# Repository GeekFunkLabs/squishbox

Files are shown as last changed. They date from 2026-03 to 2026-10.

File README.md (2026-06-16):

# SquishBox

- [Official Documentation](https://geekfunklabs.github.io/squishbox)
- [Source Repository](https://github.com/GeekFunkLabs/squishbox)

The SquishBox is a compact add-on board and enclosure for Raspberry Pi
(primarily Pi 3B+ and Pi 4) that combines:

- high-quality stereo DAC with 1/4" outputs
- MIDI in/out via TRS minijacks
- 16x2 character LCD
- pushbutton rotary encoder
- breakout GPIO for extra controls, LEDs, and peripherals

This creates a portable embedded platform for audio projects such as synths,
sound modules, pedalboard utilities, sequencers, and music players.

The software package includes ready-to-run applications plus a simple Python API
for building your own.

## Building/Obtaining

This repository includes schematics, PCB fabrication files, BOMs, and enclosure
models for users who want to build their own hardware.

Kits and pre-built units are also available from the Geek Funk Labs
[store](https://geekfunklabs.com/store).

## Installing

The SquishBox software is targeted for a Pi 3B+/4 running Raspberry Pi OS
(64-bit, based on Debian 13 "Trixie") or newer.
Other platforms may work but are not officially tested.

Before installing (even on a fresh system) it's advisable to first run
`sudo apt update && sudo apt upgrade` to update your audio stack.

To run the install script, log in as a regular user and enter:

```bash
bash <(curl -sL geekfunklabs.com/squishbox)
```

Answer the prompts, wait for install to complete,
and reboot the Pi to activate the LCD/button interface.

## Using the SquishBox

On first boot, the SquishBox starts a launcher that lets the user choose
an app to run or modify system settings.
Selections can be made by turning the rotary encoder.
Tapping the rotary encoder confirms a choice.
Pressing and holding the encoder will cancel or return to the previous
screen in most situations.
To safely shut down the SquishBox before disconnecting power,
use the "Shutdown" option in the "Exit" menu.

## Writing SquishBox Apps

The squishbox python package provides access to the LCD,
controls (buttons/encoders), outputs,
and a set of menu-driven interaction helpers.
Here is a simple example app:

```python
import squishbox

sb = squishbox.SquishBox()
card = "hw:sndrpihifiberry"

sb.lcd.clear()
sb.lcd.write("Audio Test", row=0)
while True:
    i, option = sb.menu_choose(["Noise", "Sine", "Exit"], row=1)
    if option == "Noise":
        sb.shell_cmd(f"speaker-test -l2 -c2 -D{card}")
    elif option == "Sine":
        sb.shell_cmd(f"speaker-test -l2 -c2 -tsine -D{card}")
    elif option == "Exit":
        break
```

## Support and Feature Requests

The SquishBox is under active development, and feature requests are
welcome. 

Please post requests/questions to Discussions on GitHub,
and open issues or pull requests for bugs.

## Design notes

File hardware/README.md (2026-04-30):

# SquishBox Hardware

This directory contains the design and fabrication files for the SquishBox PCB and enclosure. These files are sufficient to fabricate the PCB, source components, and 3D-print a complete enclosure.

Editable design files are also provided to support modification and customization. If anything is missing or unclear, please open a GitHub issue or contact [albedozero@geekfunklabs.com](mailto:albedozero@geekfunklabs.com).

## Directory Structure

```shell
hardware/
  pcb/
    fabrication/    # Gerbers, drill files, pick-and-place, BOM
    kicad/          # KiCad source design files
  enclosure/
    print/          # STL and 3MF files for slicing
    freecad/        # FreeCAD source design files
    step/           # STEP files for other CAD software
```

## PCB Details

The fabrication files include only surface-mount components for automated assembly. Through-hole components are intended to be sourced separately and soldered by hand.

Insert through-hole components from the side matching the silkscreen outlines.

Install the LCD module last, as it blocks access to several solder points.

### P1 Header

Unused pins from the Raspberry Pi GPIO header are broken out to P1 for attaching additional buttons/outputs. Pins 4 and 7 are connected to ground through 1k resistors, to allow connecting LEDs without additional components.

| P1 pin | pad shape | function |
|---|---|---|
|  1 | diamond | 5V |
|  2 | diamond | 3.3V |
|  3 | circle | GPIO4 |
|  4 | notched | 1k → GND |
|  5 | circle | GPIO2 (I2C SDA) |
|  6 | circle | GPIO3 (I2C SCL) |
|  7 | notched | 1k → GND |
|  8 | circle | GPIO23 |
|  9 | circle | GPIO24 |
|  10 | circle | GPIO10 |
|  11 | circle | GPIO25 |
|  12 | circle | GPIO9 |
|  13 | circle | GPIO11 |
|  14 | square | GND |

## Case Details

All parts are designed to be printed flat-side down without supports.

* PLA is sufficient, other materials may be used for desired traits
* Infill amount is not critical due to the small interior volume
* Use at least 2–3 wall layers for adequate strength

Three enclosure variants are provided:

* **basic** — Fits Raspberry Pi 3 Model B+ / Raspberry Pi 4 Model B. A Raspberry Pi 5 can fit, but not with the standard fan installed.
* **deluxe** — Fits Pi 3/4 and includes mounting points for two momentary footswitches and two LEDs, which can be connected to the P1 header on the SquishBox PCB.
* **mini** — Fits Raspberry Pi Model A+, with an enlarged cutout to accommodate wide USB cables or adapters.

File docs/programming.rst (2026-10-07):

Programming
===========

This page is a practical primer for customizing/writing SquishBox apps.

Instead of dealing directly with GPIO timing, LCD protocols,
encoder debouncing, or event queues, applications interact with
a single high-level object

.. code-block:: python

   import squishbox
   sb = squishbox.SquishBox()

From there you can:

* Write text to the LCD
* Read knob and button actions
* Present menus and prompts
* Edit text from the front panel
* Control LEDs and outputs
* Launch shell commands
* Build complete standalone hardware applications

Application Model
-----------------

Most SquishBox programs follow a simple pattern:

1. Create a ``SquishBox()`` instance
2. Start the synth/audio process
3. Draw something on the LCD
4. Wait for user input
5. Respond to that input
6. Repeat until exit

Example:

.. code-block:: python

    import squishbox

    sb = squishbox.SquishBox()
    sb.lcd.clear()
    sb.lcd.write("My Cool Synth", row=0)

    i = 0
    synth = start_synth()
    synth.select_patch(i)

    while True:
        i, action = sb.menu_choose(synth.patchnames, i=i)

        if action == None:
            break
        else:
            synth.select_patch(i)

Configuration Files
^^^^^^^^^^^^^^^^^^^

The main SquishBox configuration file ``squishboxconf.yaml`` is intended
to allow the user to change global behavior without modifying code.

The ``controls`` section defines named inputs such as buttons and encoders.
Each item describes the hardware type, GPIO settings, and event bindings.

* ``actions`` Links events to SquishBox UI actions:

  * ``inc``/``dec`` change a value/option
  * ``select`` do/confirm
  * ``back`` cancel/return
  
* ``messages`` Emits MIDI messages in response to events.
  Control change, note, and program change messages are implemented.
  Message format is ``{ctrl|note}:<channel>:<number>:<value>``
  or ``{prog}:<channel>:<value>``.

.. code-block:: yaml

    controls:
      knob1:
        type: encoder
        pins: [22, 27]
        actions: {left: dec, right: inc}
      knob1_button:
        type: button
        pin: 17
        actions: {tap: select, hold: back}    
      foot_left:
        type: button
        pin: 9
        messages: {in: ctrl:16:22:127, out: ctrl:16:22:0}

The main config file is loaded on import and stored in the ``CONFIG`` variable.
The ``load_config()`` and ``save_state()`` functions can be used
to manage config files for SquishBox apps.

.. code-block:: python

    from squishbox.config import load_config, save_state

    myconfig = load_config("myappconf.yaml")
    
    ...
    
    myconfig["last_bank_path"] = current_bank
    save_state("myappconf.yaml", myconfig)

Tokens ending with ``_path`` in config files are converted to ``pathlib.Path``
objects upon loading, and are serialized as POSIX strings when saving.

Controlling the LCD
-------------------

The built-in LCD object is available as:

.. code-block:: python

   sb.lcd

Clear the display:

.. code-block:: python

   sb.lcd.clear()

Write text:

.. code-block:: python

   sb.lcd.write("Patch Loaded", row=0)
   sb.lcd.write("Grand Piano", row=1, align="right")

Long text automatically scrolls when needed. Alignment is left by default.
Non-scrolling text can be written on top of scrolling text to create
partially-scrolling displays.

The ``timeout=`` option overlays text for a specified number of seconds:

.. code-block:: python

   sb.lcd.write("Saved", row=1, timeout=2)

This is useful for status messages.

Custom Characters
^^^^^^^^^^^^^^^^^

Characters beyond the standard "ASCII Printable" set can be defined as
custom characters in the configuration file:

.. code-block:: yaml

    glyphs_5x8:
      wifi_on: |
        -XXX-
        X---X
        --X--
        -X-X-
        -----
        --X--
        -----
        -----

A maximum of 8 unique custom characters can be displayed at once, but
an arbitrary number can be defined in the LCD object. They are displayed
using element access:

.. code-block:: python

   sb.lcd.write("WiFi status: " + sb.lcd["wifi_on"], row=0)

User Interaction
----------------

The user interaction helpers use a blocking model - they don't return
until a value is ready (unless ``timeout=`` is used). This makes it easier
to understand program flow. They all have built-in idle loops that update
scrolling elements of the LCD and provide CPU time for other processes
such as synths/audio applications.

Several menu helper functions are provided to make it easy to create apps.

Choice Menu
^^^^^^^^^^^

.. code-block:: python

   i, option = sb.menu_choose(
       ["Piano", "Organ", "Synth"],
       row=1
   )

   if option:
       sb.lcd.write(option, row=0)

Returns:

* selected index
* selected item
* item is returned as ``None`` if canceled

Confirmation Prompt
^^^^^^^^^^^^^^^^^^^

.. code-block:: python

   if sb.menu_confirm("Delete file?"):
       delete_file()

Displays a toggling check/"X" at the end of text and returns True/False.

Text Entry
^^^^^^^^^^

.. code-block:: python

   name = sb.menu_entertext("New Patch")

Useful for:

* patch names
* WiFi passwords
* filenames (with ``charset=sb.lcd.fnchars()``)
* labels

Returns the entered text. Use ``menu_confirm()`` afterward to let the user
confirm/cancel the input if desired.

File Browser
^^^^^^^^^^^^

.. code-block:: python

   path = sb.menu_choosefile("/home/pi/patches", ext=[".yaml"])

This provides a simple two-line browser for selecting files. Returns 
a ``Path()`` object for the chosen file, or the last-browsed directory if
canceled. 

System Settings Menu
^^^^^^^^^^^^^^^^^^^^

.. code-block:: python

    if sb.menu_systemsettings() == "shell":
        sys.exit()

This provides a unified system settings menu for LCD, WiFi, and MIDI
settings. It also allows the user to shutdown/reboot the Pi, or exit
the current program.

Direct Action Handling
^^^^^^^^^^^^^^^^^^^^^^

For more complex user interfaces (e.g. vertically-scrollable menus, screens
with active status indicators and/or custom actions), the ``get_action()``
function can be used to create interaction loops.

Incoming actions are stored in a queue, and ``get_action()``
retrieves them FIFO-style, blocking while the queue is empty
(or until ``timeout`` is exceeded).

.. code-block:: python

    # display scrollable multi-line output

    out = text.splitlines() # some multi-line text
    irow, crow = 0, 0

    while True:
        for i in range(irow, min(irow + ROWS, len(out))):
            sb.lcd.write(
                (out[i] if i < len(out) else "").ljust(COLS),
                row=i - irow
            )
        match sb.get_action():
            case "inc":
                crow += 1
                if crow == ROWS or crow == len(out):
                    crow -= 1
                    irow = min(irow + 1, len(out) - ROWS) % len(out)
            case "dec":
                crow -= 1
                if crow < 0:
                    crow = 0
                    irow = max(irow - 1, 0)
            case "select" | "back":
                break

The ``add_action()`` function can be used as a callback to send events
to be picked up by ``get_action()``. MIDI events are a common case.

.. code-block:: python

    def monitor_midi():
        while True:
            event = midi_input()
            sb.add_action(event)

    ...

    while True:
        sb.lcd.write(patchnames[i], row=0)
        action = sb.get_action()
        if action == "inc":
            i = (i + 1) % len(patchnames)
            select_patch(i)
        elif action == "dec":
            i = (i - 1) % len(patchnames)
            select_patch(i)
        elif isinstance(action, MidiEvent):
            sb.lcd.write(str(action), row=1, timeout=2)

Controlling Outputs
^^^^^^^^^^^^^^^^^^^

Outputs are defined in the configuration file:

.. code-block:: yaml

    outputs:
      led_blinker: {type: binary, pin: 23}
      led_fader: {type: pwm, pin: 4, level: 60}

Configured outputs are available through ``sb.outputs``.

Example:

.. code-block:: python

    sb.outputs["led_blinker"].on()
    sb.outputs["led_blinker"].off()

PWM outputs expose a ``level`` property representing duty cycle percentage.

.. code-block:: python

    sb.outputs["led_fader"].level = 75

Miscellaneous Tools
-------------------

Controlling MIDI Applications
^^^^^^^^^^^^^^^^^^^^^^^^^^^^^

The ``sb.midi.wrap()`` method returns a ``SquishBoxMidiWrapper`` object
that catches all MIDI messages destined for the wrapped port, allowing
apps to filter/modify them or produce feedback on the LCD.

.. code-block:: python

    wrapper = sb.midi.wrap("mysynth.exe:0(MIDI in)")

    ...

    evt = wrapper.receive()
    evt.value *= 2
    wrapper.send(evt)

Running Shell Commands
^^^^^^^^^^^^^^^^^^^^^^

The ``shell_cmd()`` method executes a string as a shell command and
returns the output as an ASCII-encoded string.

.. code-block:: python

   result = sb.shell_cmd("hostname -I")
   sb.lcd.write(result, row=1)

Useful for:

* audio tools
* system commands
* WiFi utilities
* file conversion
* launching synth engines

Long Running Tasks
^^^^^^^^^^^^^^^^^^

Use the activity spinner while work is in progress:

.. code-block:: python

   with sb.lcd.activity("Loading..."):
       load_large_patch()

This gives visual feedback on the LCD while your task runs.

Error Handling
^^^^^^^^^^^^^^

Unhandled exceptions are automatically displayed on the LCD before the
application exits. To handle errors gracefully (i.e. without exiting):

.. code-block:: python

   try:
       load_patch(name)
   except Exception as e:
       sb.display_error(e, "Load failed")

API Reference
-------------

The classes and functions below form the programming interface
for the squishbox package.

.. toctree::
   :maxdepth: 2

   api/squishbox
   api/hardware
   api/midi
   api/config

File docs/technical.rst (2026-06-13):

Technical Docs
==============

This section collects miscellaneous hardware and software documentation
for users modifying or servicing the SquishBox.

Schematic
---------

The full schematic is available below. Through-hole components are
crossed out to indicate they are sourced separately.

.. only:: html

    

    PDF version:
    :download:`Download <images/squishbox8_schem.pdf>`

.. only:: latex

    

This Interactive Bill of Materials allows part identification,
placement lookup, and assembly cross-referencing.

`Open Interactive BOM <_static/squishbox8_ibom.html>`__

PCB
---

Download manufacturing files from
https://github.com/GeekFunkLabs/squishbox/tree/main/hardware/pcb/fabrication.

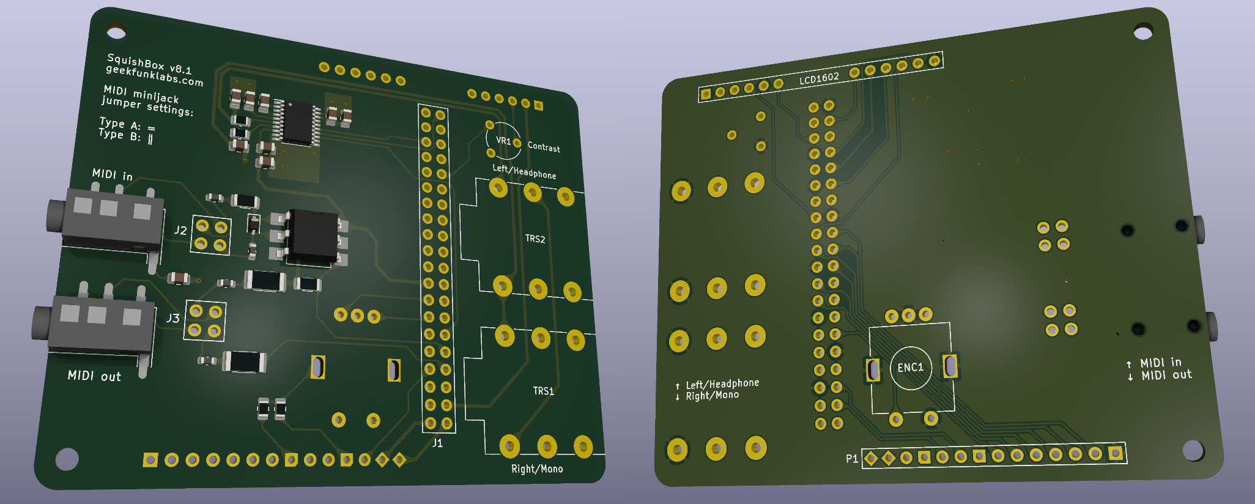
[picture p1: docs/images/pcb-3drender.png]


   3D Render of SquishBox PCB with surface-mount components

P1 Header
^^^^^^^^^

Unused Raspberry Pi GPIO pins are broken out to header **P1**
for switches, LEDs, sensors, and other add-ons.

Pins **4** and **7** include built-in 1k pull-down resistors to ground,
allowing LEDs to be connected directly.

======  =========  ==================
P1 Pin  Pad Shape  Function
======  =========  ==================
1       diamond    5V
2       diamond    3.3V
3       circle     GPIO4
4       notched    GND via 1k
5       circle     GPIO2 (I2C SDA)
6       circle     GPIO3 (I2C SCL)
7       notched    GND via 1k
8       circle     GPIO23
9       circle     GPIO24
10      circle     GPIO10
11      circle     GPIO25
12      circle     GPIO9
13      circle     GPIO11
14      square     GND
======  =========  ==================

System Setup
------------

The installer script configures a complete SquishBox system by performing
the following tasks:

* Installs system-level dependencies using Debian packages
* Creates a Python virtual environment and installs SquishBox and
  optional Python components
* Configures boot settings for supported hardware features such as
  audio devices and serial MIDI bridges
* Applies user-level configuration:

  * Updates group membership and permissions
  * Enables required system services
  * Creates convenience command aliases

Command Aliases
^^^^^^^^^^^^^^^

The installer script creates several convenience aliases for working
with the SquishBox environment:

* ``squishbox-python`` - Runs Python inside the SquishBox virtual environment
* ``squishbox-pip`` - Installs or updates Python packages in the SquishBox virtual environment
* ``squishbox-launcher`` - Starts the SquishBox launcher in the current shell
* ``squishbox-start`` - Starts the SquishBox background service
* ``squishbox-stop`` - Stops the SquishBox background service
* ``squishbox-status`` - Displays the status of the SquishBox background service

Updates
^^^^^^^

Most application updates can be installed directly through `pip` inside
the SquishBox virtual environment: ::

    squishbox-pip install -U squishbox

To also upgrade optional components and their dependencies: ::

    squishbox-pip install -U squishbox[full]

The installer script may be run again at any time to apply system-level
changes, install new dependencies, or update system configuration.

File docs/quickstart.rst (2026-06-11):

Quick Start
===========

Follow the steps below to get a SquishBox up and running quickly. Some or all
of the hardware steps can be skipped by purchasing a kit or fully assembled
unit from the Geek Funk Labs `store <https://geekfunklabs.com/store>`__.

1. `Fabricating PCB and Enclosure`_
2. `Putting it Together`_
3. `Installing the Software`_
4. `Basic Usage`_

Fabricating PCB and Enclosure
-----------------------------

The PCB fabrication files include only the surface-mount components for
automated assembly. Through-hole components are intended to be sourced
separately and soldered by hand.

Load the enclosure model files in ``hardware/enclosure/`` into your preferred
slicer software for 3D printing. All parts are designed to print flat-side
down without supports.

Three enclosure variants are provided:

* **basic** — Fits Raspberry Pi 3 Model B+ and Raspberry Pi 4 Model B.
  A Raspberry Pi 5 can fit, but not with the standard fan installed.
* **deluxe** — Fits Pi 3/4 and adds mounting points for two momentary
  footswitches and two LEDs, which can be connected to the P1 header on
  the SquishBox PCB.
* **mini** — Fits Raspberry Pi Model A+, with an enlarged cutout to
  accommodate wide USB cables or adapters.

Recommended print notes:

* PLA is sufficient, though other materials may be used for specific traits
* Infill is not critical due to the small internal volume
* Use at least 2–3 wall layers for good strength

Putting it Together
-------------------

Insert the through-hole components from the side of the PCB with the matching
silkscreen outlines, then solder them in place.

Install the LCD module last, as it blocks access to several other solder
points.

Mount the completed PCB into the enclosure by passing the rotary encoder shaft
and audio jacks through the corresponding openings, then secure them with the
included washers and nuts.

Install the Raspberry Pi by plugging its GPIO header into the 2x20 socket,
then fasten the lid in place.

Installing the Software
-----------------------

The SquishBox software is targeted for a Pi 3B+/4 running Raspberry Pi OS
(64-bit, based on Debian 13 "Trixie") or newer.

Before installing it's advisable to perform an upgrade to
make sure your audio stack is up to date: ::

    sudo apt update
    sudo apt upgrade

To run the install script, log in as a regular user and enter: ::

    bash <(curl -sL geekfunklabs.com/squishbox)

Answer the prompts, wait for the installation to complete, then reboot the Pi
to activate the LCD and control interface.

Basic Usage
-----------

On first boot, the SquishBox launches a menu system for starting apps or
changing system settings.

Controls:

* Turn the rotary encoder to move through menu items
* Tap the encoder to confirm a selection
* Press and hold the encoder to cancel or return to the previous screen

To safely power down before disconnecting power, choose **Shutdown** from the
**Exit** menu.

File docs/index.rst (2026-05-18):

SquishBox Documentation
=======================

The SquishBox is an add-on board for the Raspberry Pi 3B+/4 that bundles
a DAC, 1/4" ouputs, MIDI in/out with minijacks, a 16x2 LCD, and a
pushbutton rotary encoder.
It is designed to be an embedded computer for audio applications,
such as a synth module or audio player.
It has a python API for easy access to buttons, LCD, and system functions.
Several pre-built apps are included.

* `Official Documentation <https://geekfunklabs.github.io/squishbox>`__
* `Source Repository <https://github.com/GeekFunkLabs/squishbox>`__

The SquishBox can be fabricated from scratch using the included design
files, or obtained as a kit or fully assembled device from the
Geek Funk Labs `store <https://geekfunklabs.com/store>`__.
Software is installed in an existing Raspberry Pi OS using a
command-line installer script.

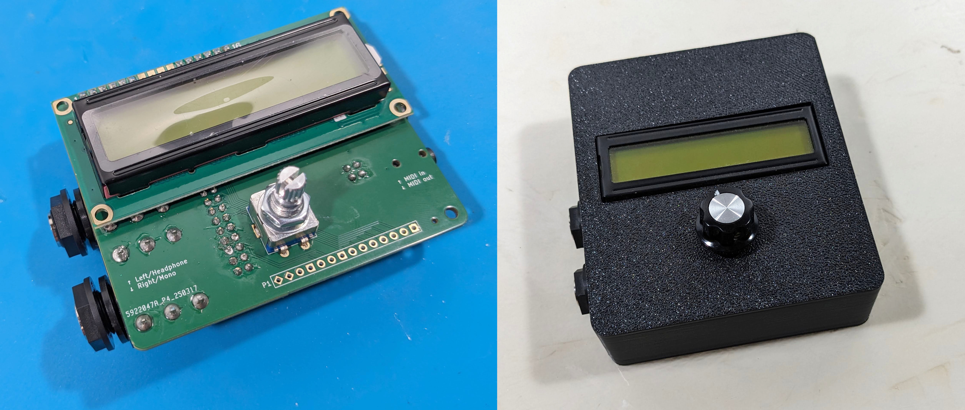
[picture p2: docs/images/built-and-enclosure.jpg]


   Assembled SquishBox electronics (left) and enclosure (right)

.. toctree::
   :maxdepth: 2
   :caption: Contents:

   quickstart
   userguide
   assembly
   programming
   technical

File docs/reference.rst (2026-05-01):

Reference
=========

PCB
---

This section collects hardware documentation, fabrication references,
and connector pinouts for users modifying or servicing the SquishBox.

Download manufacturing files from
https://github.com/GeekFunkLabs/squishbox/tree/main/hardware/pcb/fabrication.



   3D Render of SquishBox PCB with surface-mount components

Bill of Materials
^^^^^^^^^^^^^^^^^

The Interactive BOM allows part identification, placement lookup,
and assembly cross-referencing.

`Open Interactive BOM <_static/squishbox8_ibom.html>`__

Schematic
^^^^^^^^^

The full schematic is available below. Through-hole components are
crossed out to indicate they are sourced separately.

.. only:: html

    

    PDF version:
    :download:`Download <images/squishbox8_schem.pdf>`

.. only:: latex

    

P1 Header
^^^^^^^^^

Unused Raspberry Pi GPIO pins are broken out to header **P1**
for switches, LEDs, sensors, and other add-ons.

Pins **4** and **7** include built-in 1k pull-down resistors to ground,
allowing LEDs to be connected directly.

======  =========  ==================
P1 Pin  Pad Shape  Function
======  =========  ==================
1       diamond    5V
2       diamond    3.3V
3       circle     GPIO4
4       notched    GPIO17 via 1k to GND
5       circle     GPIO2 (I2C SDA)
6       circle     GPIO3 (I2C SCL)
7       notched    GPIO27 via 1k to GND
8       circle     GPIO23
9       circle     GPIO24
10      circle     GPIO10
11      circle     GPIO25
12      circle     GPIO9
13      circle     GPIO11
14      square     GND
======  =========  ==================

API
---

The classes and functions below form the programming interface
for the squishbox package.

.. toctree::
   :maxdepth: 2

   api/squishbox
   api/hardware
   api/config

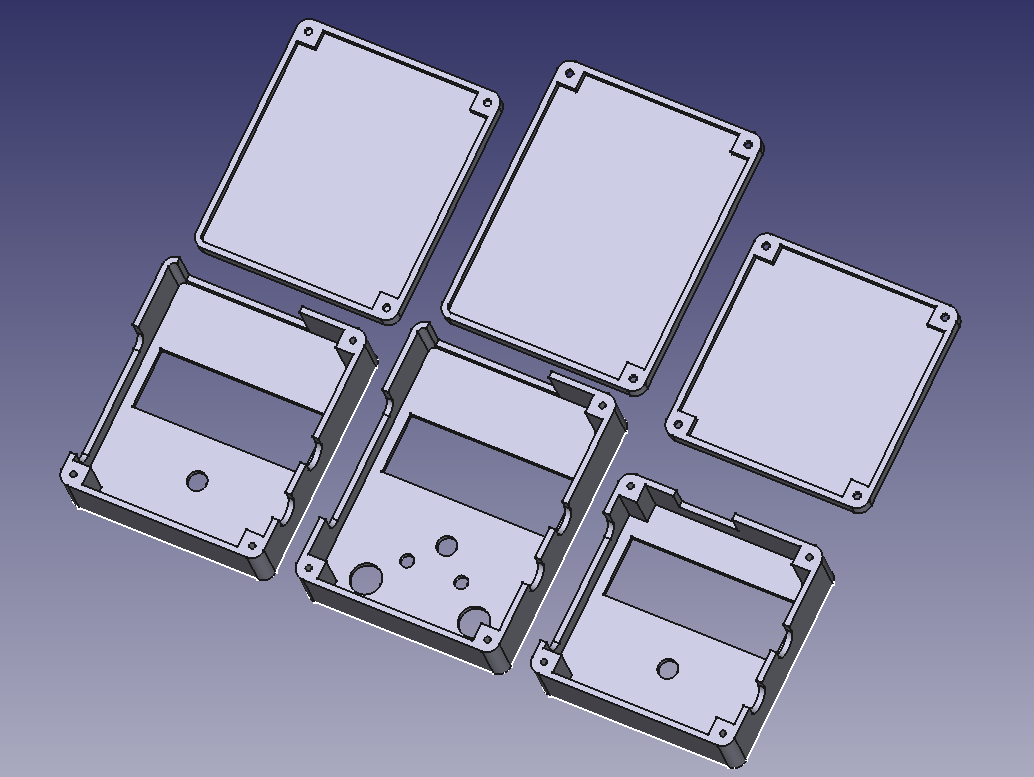
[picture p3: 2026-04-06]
hardware/enclosure/cases.png

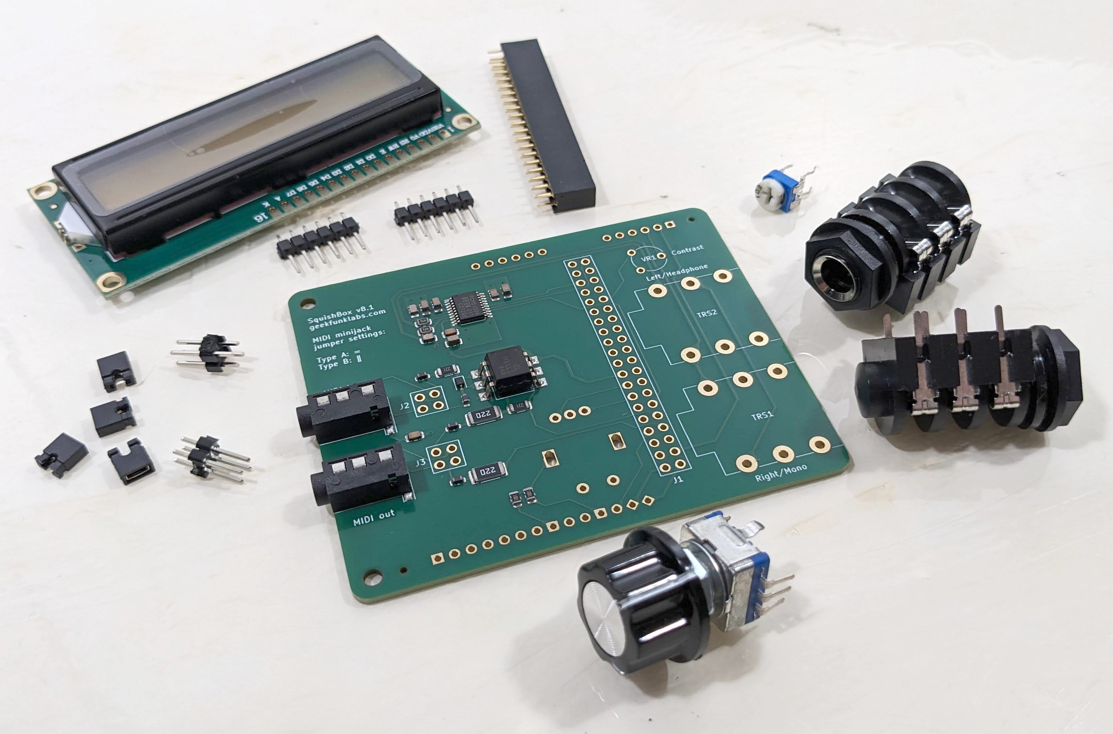
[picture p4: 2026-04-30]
docs/images/squishbox-kit.jpg

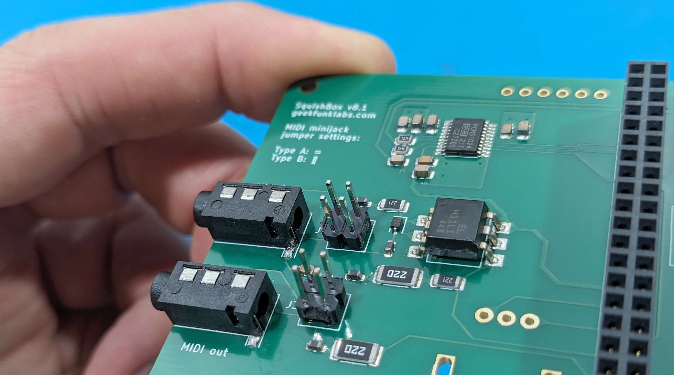
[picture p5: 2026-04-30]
docs/images/midi-type-jumpers.jpg

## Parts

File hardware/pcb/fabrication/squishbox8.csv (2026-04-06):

Id | Designator | Footprint | Quantity | Designation | Supplier and ref
1 | C1, C4, C7 | C_0805_2012Metric | 3 | 100 nF
2 | C2, C8 | C_0805_2012Metric | 2 | 10 uF
3 | C5, C6 | C_0805_2012Metric | 2 | 2.2 uF
4 | C9, C10 | C_0805_2012Metric | 2 | 2.2 nF
5 | D1 | D_SOD-323 | 1 | 1N4148WS
6 | ENC1 | RotaryEncoder_Alps_EC11E-Switch_Vertical_H20mm | 1 | RotEnc_Sw
7 | J1 | PinSocket_2x20_P2.54mm_Vertical | 1 | Raspberry_Pi_2_3
8 | J2, J3 | PinHeader_2x02_P2.54mm_Vertical | 2 | Conn_02x02_Odd_Even
9 | J4, J5 | Jack_3.5mm_KoreanHropartsElec_PJ-320D-4A_Horizontal | 2 | AudioJack4
10 | L1, L2, L3, L4 | L_0603_1608Metric | 4 | L_Ferrite
11 | P1 | PinHeader_1x14_P2.54mm_Vertical | 1 | Conn_01x14_Pin
12 | R1, R2 | R_0805_2012Metric | 2 | 470
13 | R3, R4 | R_0805_2012Metric | 2 | 1k
14 | R5, R6 | R_2010_5025Metric | 2 | 22
15 | R7, R8 | R_1206_3216Metric | 2 | 220
16 | TRS1, TRS2 | Jack_6.35mm_Neutrik_NMJ6HFD4_Horizontal | 2 | AudioJack3_Switch
17 | U1 | TSSOP-20_4.4x6.5mm_P0.65mm | 1 | PCM5102
18 | U2 | PinSocket_1x16_P2.54mm_Vertical | 1 | LCD1602
19 | U3 | SMDIP-6_W9.53mm | 1 | H11L1
20 | VR1 | Potentiometer_Piher_PT-6-V_Vertical | 1 | 10k

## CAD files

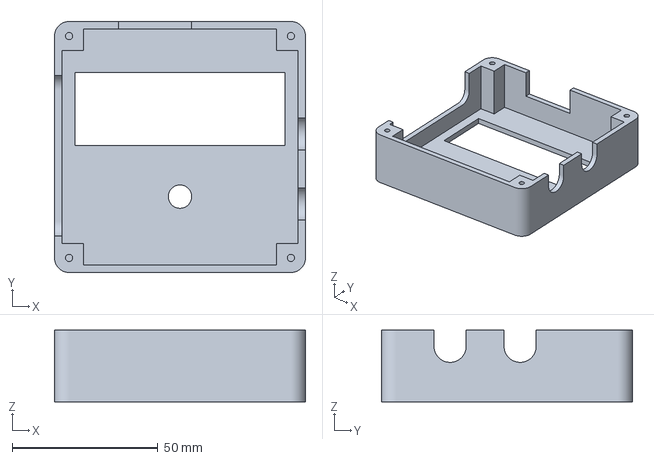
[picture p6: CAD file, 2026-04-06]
hardware/enclosure/print/mini-case-body.3mf
86.0 x 86.0 x 24.5 mm

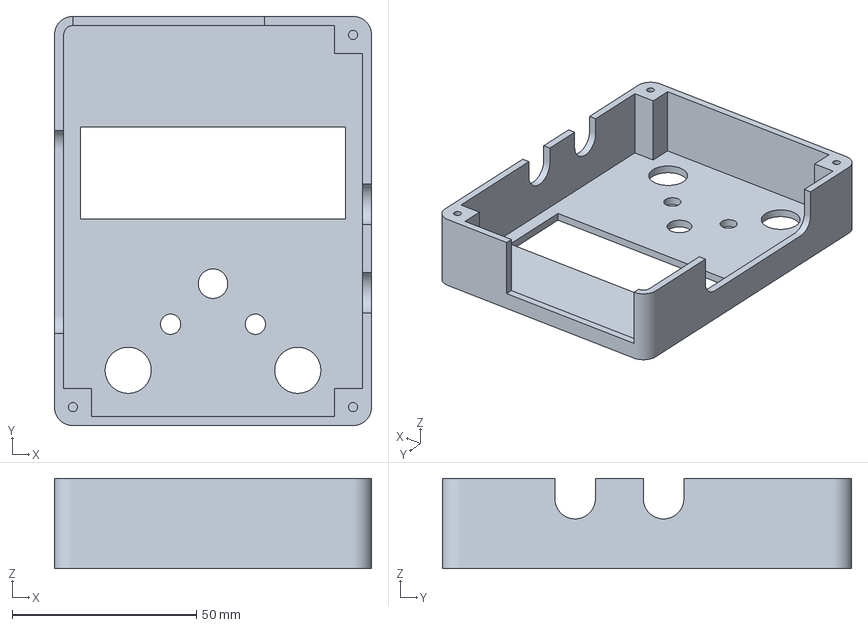
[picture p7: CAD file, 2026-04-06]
hardware/enclosure/print/deluxe-case-body.3mf
86.0 x 111.0 x 24.5 mm

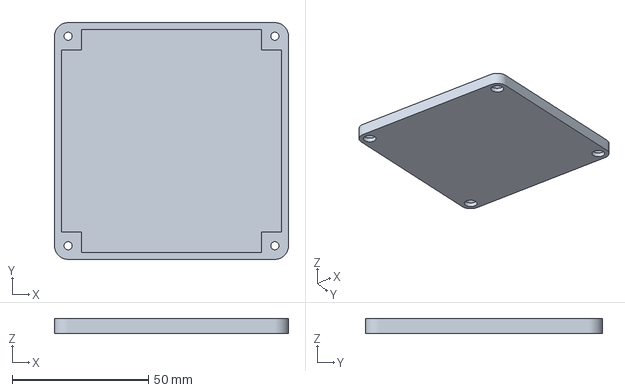
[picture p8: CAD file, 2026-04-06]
hardware/enclosure/print/ mini-case-lid.3mf
86.0 x 87.0 x 5.50 mm

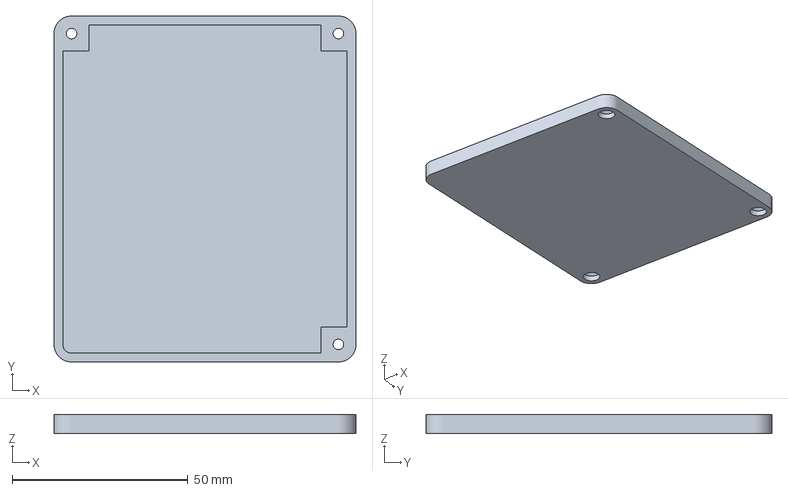
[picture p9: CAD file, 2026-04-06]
hardware/enclosure/print/basic-case-lid.3mf
86.0 x 98.5 x 5.50 mm

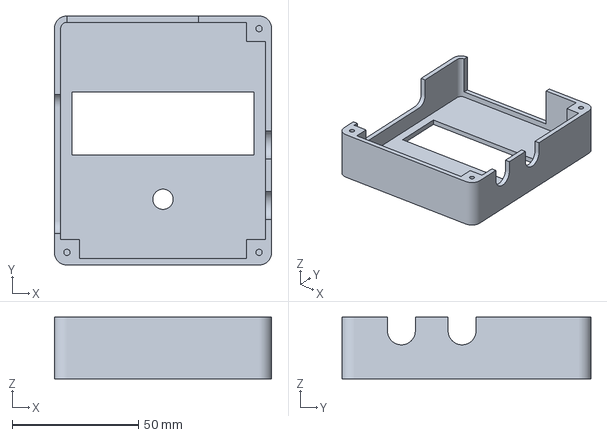
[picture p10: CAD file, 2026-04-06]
hardware/enclosure/print/basic-case-body.3mf
86.0 x 98.5 x 24.5 mm

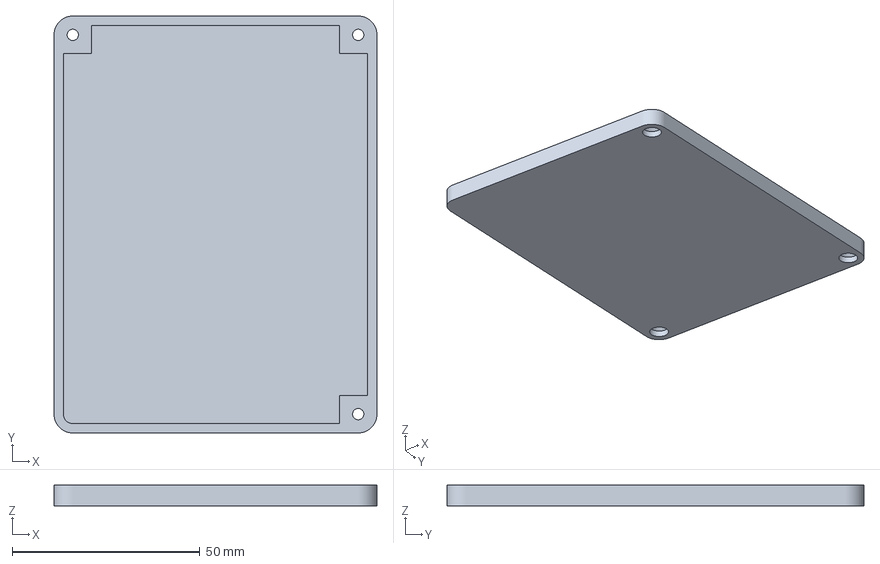
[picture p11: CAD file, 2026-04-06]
hardware/enclosure/print/deluxe-case-lid.3mf
86.0 x 111.0 x 5.50 mm

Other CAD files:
hardware/enclosure/freecad/squishbox_case_v11.FCStd
hardware/enclosure/print/basic-case-body.stl
hardware/enclosure/print/basic-case-lid.stl
hardware/enclosure/print/deluxe-case-body.stl
hardware/enclosure/print/deluxe-case-lid.stl
hardware/enclosure/print/mini-case-body.stl
hardware/enclosure/print/mini-case-lid.stl

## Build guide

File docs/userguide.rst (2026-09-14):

User Guide
==========

When powered on, the SquishBox starts a launcher that allows you to run
applications, browse tools, or modify system settings.

Navigation is designed to be simple and usable without a keyboard or display
larger than the built-in LCD.

Basic Controls
--------------

The primary control is the pushbutton rotary encoder.

* Turn the encoder to move through menus or adjust values
* Tap the encoder to confirm a selection
* Press and hold the encoder to cancel, go back, or exit the current screen

Most built-in applications follow this same control scheme.

Text Entry
^^^^^^^^^^

The SquishBox includes an on-screen text entry mode for naming files,
editing settings, and entering text without a keyboard.

Pressing the encoder toggles between two cursor modes:

* **Blinking block cursor** — Move the cursor position by turning the encoder
* **Underline cursor** — Change the current character by turning the encoder

This allows text to be entered entirely from the front panel.

If a USB or wireless keyboard is connected to the Raspberry Pi, keyboard input
is also accepted anywhere text entry is available.

Safe Shutdown
^^^^^^^^^^^^^

To safely power down the system before disconnecting power, choose
**Shutdown** from the **Exit** menu.

This helps prevent filesystem corruption or SD card damage.

Software
--------

File locations
^^^^^^^^^^^^^^

By default, configuration and media files for the SquishBox are organized
in the folder structure shown below. Directories are created by apps
as needed.

.. code-block:: text

    ~/Squishbox/
     ├── config/
     ├── banks/
     │   ├── fluidpatcher/
     │   └── amsynth/
     ├── media/
     │   ├── sounds/
     │   ├── midi/
     │   └── music/
     ├── playlists/
     └── sets/

The main configuration file is stored at ``config/squishboxconf.yaml``,
and defines settings such as:

* LCD configuration
* UI timings
* Inputs/Outputs and bindings
* Custom LCD characters

The ``config`` directory is also the default location for app configuration files.

User Interface
^^^^^^^^^^^^^^

The SquishBox launcher starts automatically on boot and serves as the main entry
point for applications and utilities. It provides a menu for launching programs
and scripts, and also acts as a fallback environment if an application exits or
crashes. Additional directories containing user scripts can be added using the
``app_dirs`` configuration option.

Most applications, including the launcher, provide access to shared system menus
for configuring MIDI, Wi-Fi, LCD settings, and power options.

MIDI Routing
""""""""""""

The SquishBox manages connections between MIDI devices and applications
as defined in the ``midi_connections`` section of the configuration file.

.. code-block:: yaml

    midi_connections:
    - DONNER DMK25Pro:0(DONNER DMK25Pro MIDI 1)>FluidPatcher:0(FluidPatcher)
    - QuNexus:0(QuNexus Control Surface)>SquishBox minijacks:1(SquishBox minijacks Out)

These settings can be easily managed from the MIDI Settings menu by first
selecting the MIDI input device, then selecting the destination.

Applications that use MIDI internally (such as ``fpatcherbox``) typically
appear as available destinations only while they are running.

The port ``SquishBox MIDI out`` sends messages from any hardware controls
that are configured to do so (e.g. footswitches). The ``SquishBox MIDI in``
port is used by the system to detect when new devices are connected.

Special ``any`` entries may be used to create automatic routing rules. For
example:

* Connect any MIDI device to a specific application
* Connect a specific MIDI device to any application
* Automatically connect any device to any available application
  (``any>any`` - the default behavior)

Wi-Fi Settings
""""""""""""""

The Wi-Fi Settings menu allows scanning for wireless networks, connecting to
access points, and enabling or disabling Wi-Fi entirely.

Most applications display a Wi-Fi status icon. This icon indicates whether the
Wi-Fi hardware is enabled, not whether the system is currently connected to a
network.

Disabling Wi-Fi may improve reliability in some situations, since Wi-Fi scanning
and background network activity can increase memory usage and occasionally
interfere with real-time audio applications.

Power Menu
""""""""""

The Power menu provides options to reboot or shut down the system,
as well as a **Shell** option to exit the currently running application
and return to the launcher.

If the system is rebooted or powered off while an application is running, the
launcher automatically restarts that application on the next boot. This allows
applications such as ``amsynthbox`` or ``fpatcherbox`` to behave like dedicated
standalone instruments that automatically resume after power cycling.

Included Apps
^^^^^^^^^^^^^

The included applications serve two purposes:

* Fully supported tools and audio programs for daily use
* Reference examples for developers using the SquishBox Python API

Bug reports and feature requests can be submitted through the project GitHub
issue tracker.

``fpatcherbox``
"""""""""""""""

Flexible synth and sound module built around the
`FluidSynth <https://www.fluidsynth.org/>`__ engine using the
`FluidPatcher <https://geekfunklabs.github.io/fluidpatcher/>`__ Python package.

The interface allows:

* Selecting patches, adding/removing/saving patches, and loading/saving banks
* Adjusting FluidSynth's built-in reverb and chorus effects
* Live selection of soundfont presets on any channel
* Creation of MIDI keyboard routing layers on-the-fly

Pressing and holding the encoder at the main screen toggles between
displaying MIDI activity and full MIDI message information.

The app recognizes several custom router rule parameters:

``lcdwrite``
    Writes a message on the LCD when a MIDI event matches the rule.
    If the rule also has a ``format`` parameter of the form ``w.n``,
    the event value is written with the specified width and number of
    decimal places.

``setpin``
    Sets the named output, as defined in the SquishBox config file.
    Can be used to turn an LED on/off in response to a MIDI event.

``patch``
    Applies a patch by name or increments the current patch by an amount.

``amsynthbox`` 
""""""""""""""

Front-end wrapper for the amsynth analog-modeling synthesizer.

All synth parameters can be adjusted using the menu, or bound to
MIDI control change events using the **MIDI Learn** option.
The ``midi_channel`` option in the configuration file sets the MIDI channel
amsynth will respond to. A value of ``0`` responds to any channel.

``trackbox``
""""""""""""

Playlist-based music player with live track reordering and quick cuts.
Most types of audio files can be played, and are stored in ``media/music/``
by default. The root location for music is set using the ``tracks_path``
item in the configuration file.

The list of music files to play can be edited from the **Edit Tracklist**
option in the menu. Track lists are saved as YAML files.

.. code-block:: yaml

    tracks_path: chill
    first: 0
    tracks:
    - file: Hotel Pools - Melt.mp3
    - file: downloadedfile1823.mp3
      name: Mallsoft Vibes
      start: 8:31
      end: 12:15
    - file: synthwave_mixdown.wav
      name: My Chill Beats
      level: 0.8
      
Tracklists can also have a ``tracks_path`` parameter that is relative
to the config file value or absolute. Tracklists start at the last
played track, or the index given by ``first`` if present.

``sbedit``
""""""""""

Lightweight text editor that supports both encoder input and keyboards.
Useful for editing config files or making changes to banks. When scrolling
through lines, the line number is flashed at the left edge of the screen.
Tapping the encoder edits the current line. Pressing and holding the encoder
opens a menu for loading/saving files or inserting/deleting rows.

``sbcommander``
"""""""""""""""

File manager for copying, moving, renaming, deleting files, and running
shell commands. Able to mount/unmount USB drives and copy files,
making it a useful tool for managing SquishBox content without a network
connection.

Select files to act upon using the **Choose File(s)..** menu option. Canceling
file selection chooses the current directory, allowing selection of multiple
files or the entire directory tree.

Shell commands can be entered using encoder input or a keyboard. If file(s)
are currently selected, they are added as arguments at the end of the command.
The output of the command is displayed on the LCD and can be
scrolled by turning the encoder.

``glyphedit``
"""""""""""""

Utility for creating and editing custom LCD glyph characters.

Hardware Connections
--------------------

Audio Outputs
^^^^^^^^^^^^^

The SquishBox provides two 1/4" audio output jacks.

Physical orientation:

* **Rear jack** = Left / Headphone output
* **Front jack** = Right / Mono output

(When viewed face-on, these appear on the left and right sides respectively.)

Behavior:

* If only the **Right / Mono** jack is connected, left and right channels are
  summed to mono on that output.
* If only the **Left / Headphone** jack is connected, stereo audio is routed to
  the tip and sleeve of a TRS connector for headphone use.

The PCB silkscreen also labels both jacks.

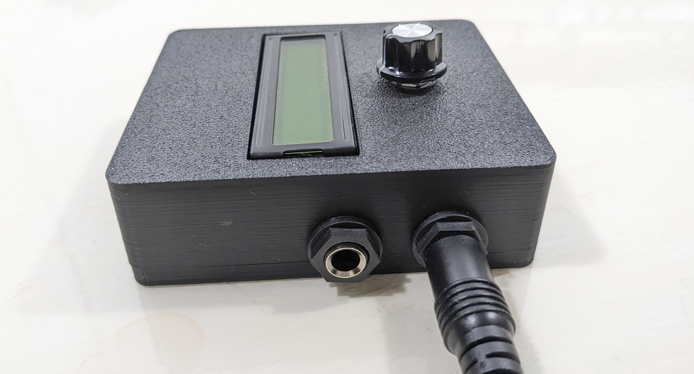
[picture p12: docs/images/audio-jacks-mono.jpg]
1/4" cable plugged into right audio port

   
   Audio ports in mono connection mode

MIDI TRS Ports
^^^^^^^^^^^^^^

The SquishBox includes MIDI input and output on 3.5 mm TRS minijacks.

Physical orientation:

* **Front jack** = MIDI Out
* **Rear jack** = MIDI In

(When viewed face-on, MIDI In is on the right.)

The PCB silkscreen also identifies each port.

Headers with jumper blocks allow the MIDI jacks to be configured for either
TRS MIDI wiring standard:

* **Type A** = horizontal jumper position ( = )
* **Type B** = vertical jumper position ( ‖ )

Set both jumpers to match the equipment you are connecting.

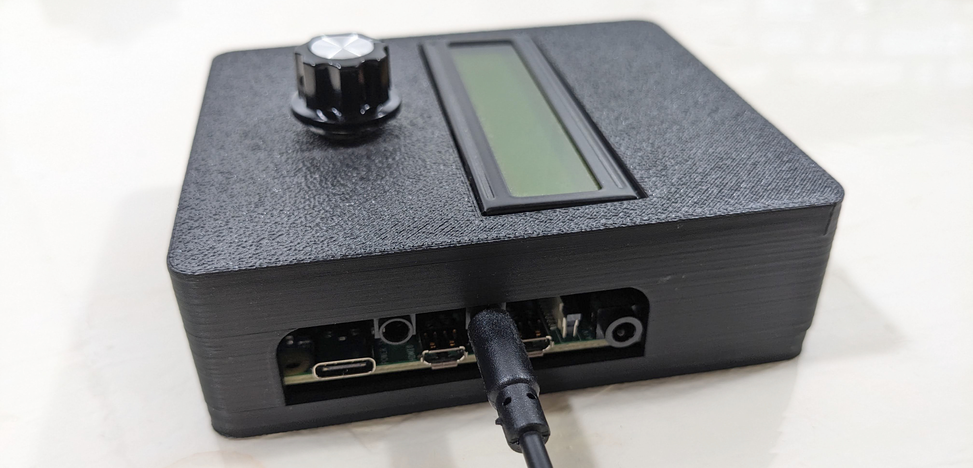
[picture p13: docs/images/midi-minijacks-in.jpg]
1/8" TRS cable plugged into right minijack

   
   Connection to MIDI IN minijack

Display Contrast Adjustment
^^^^^^^^^^^^^^^^^^^^^^^^^^^

The LCD contrast trimmer is accessible with the Raspberry Pi installed and the
rear cover removed.

Use a small screwdriver to adjust the trimmer for the best display clarity.

Contrast is controlled by both:

* The hardware trimmer potentiometer
* Software contrast settings

For best results, install the software first, then adjust the trimmer so the
software setting has a useful adjustment range.

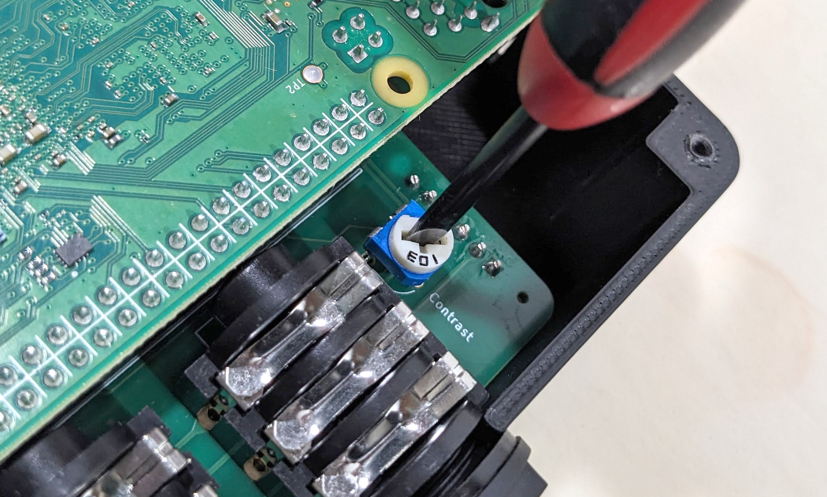
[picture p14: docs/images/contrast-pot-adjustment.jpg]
screwdriver adjusting hardware contrast potentiometer


   Adjustment of hardware contrast

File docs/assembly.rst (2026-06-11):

Assembly
========

This section explains how to assemble a SquishBox from a kit, or from
individually sourced parts after obtaining a fabricated PCB, printing an
enclosure, and gathering the required through-hole components.

Components
----------

In addition to the PCB (with surface-mount components pre-installed) and the
3D-printed PLA enclosure, a standard SquishBox kit includes:

    A. 16x2 character LCD
    B. 1x6 male header strips (2)
    C. 2x20 female header
    D. 10K trimmer potentiometer
    E. 1/4" TRS audio jacks (2)
    F. 2x2 male headers (2)
    G. Jumper blocks (2)
    H. Rotary pushbutton encoder + knob

Optional / Deluxe model:

    J. Momentary footswitches (2)
    K. 5mm LEDs (2)

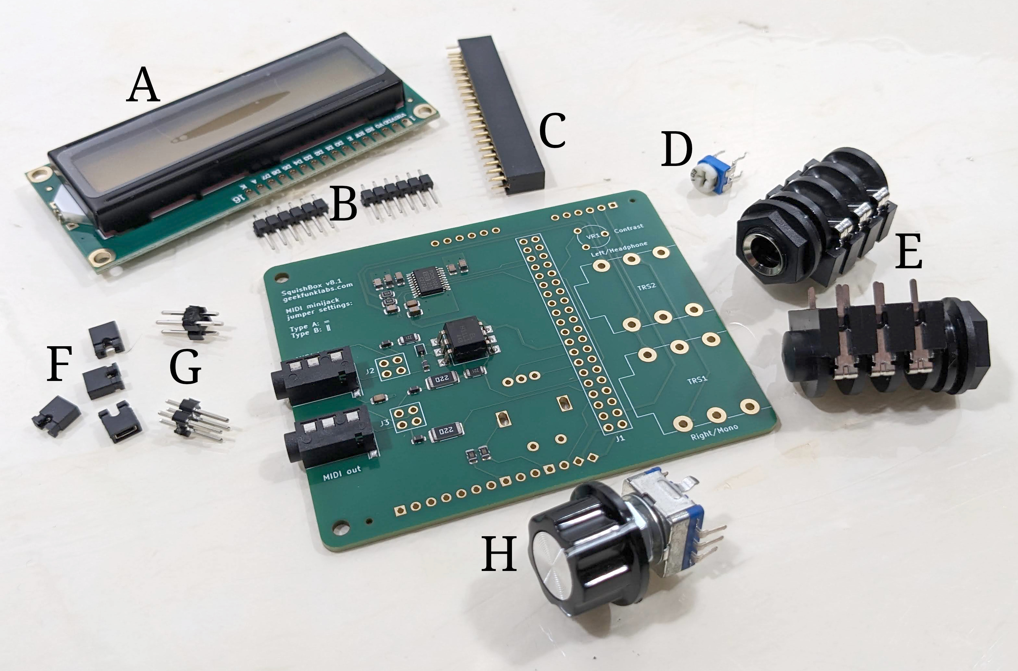
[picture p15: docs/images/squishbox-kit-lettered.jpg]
Photo of SquishBox kit components


   Through-hole components for the SquishBox

Electronics
-----------

General soldering tips:

* Install components on the side of the PCB with the matching silkscreen outline.
* Seat components flush against the PCB, especially the rotary encoder,
  audio jacks, and 2x20 header, so everything aligns properly with the enclosure.
* Install the LCD last, as it covers several other solder points.

PCB Orientation
^^^^^^^^^^^^^^^

The surface-mount components are on the PCB "bottom" side, which faces the
Raspberry Pi when installed.

Install these parts on the bottom side:

* Audio jacks
* 2x2 headers
* 2x20 female header
* Trimmer potentiometer

Install these parts on the top side:

* Rotary encoder
* LCD module (last)

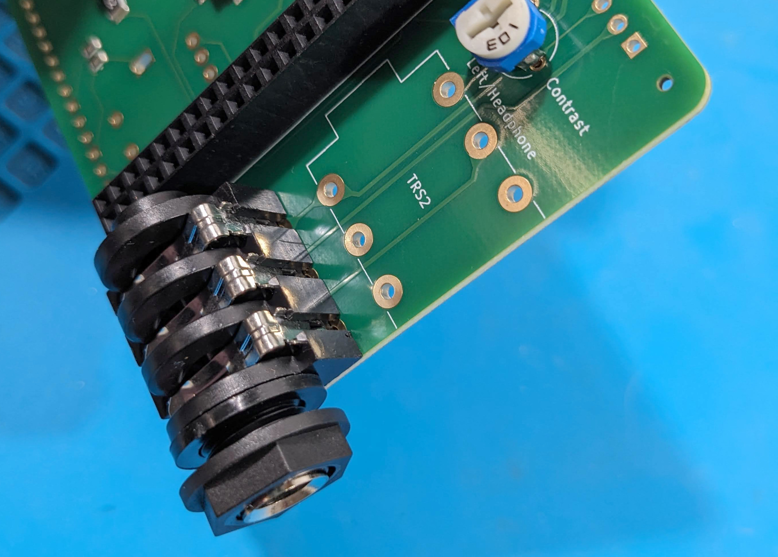
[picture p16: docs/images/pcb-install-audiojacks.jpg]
audio jacks flush mounted to bottom side of PCB


   Proper component mounting

MIDI Jumper Configuration
^^^^^^^^^^^^^^^^^^^^^^^^^

Headers J2 and J3 configure the MIDI TRS jacks for Type A or Type B wiring
using jumper blocks.

As marked on the silkscreen:

* Type A: Horizontal connection ( = )
* Type B: Vertical connection ( ‖ )

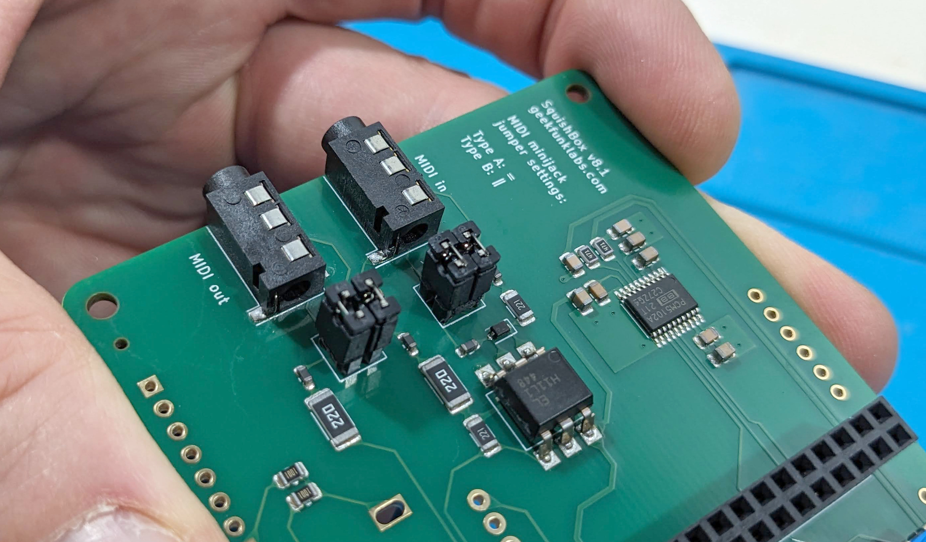
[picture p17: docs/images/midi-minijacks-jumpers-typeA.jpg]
jumpers installed in horizontal position

   
   MIDI minijack jumpers in type A configuration

LCD Header
^^^^^^^^^^

The center four LCD pads (D0-D3) are unused.

Solder the 1x6 male header strips to the outer pads at each end of the LCD
connector.

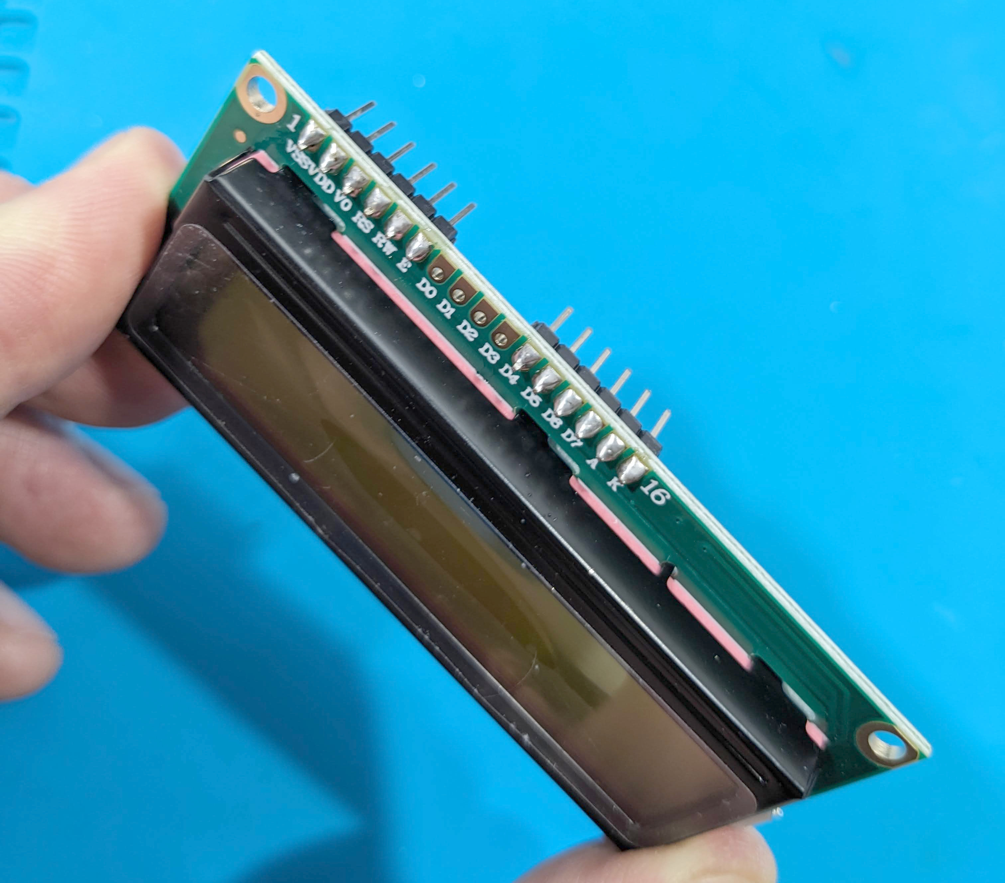
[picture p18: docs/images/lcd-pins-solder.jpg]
LCD with male headers soldered to outer 6 pads on each end

   
   Correct installation of pins to LCD connector

Deluxe Components
^^^^^^^^^^^^^^^^^

The Deluxe model adds two LEDs and two momentary footswitches.

LED Installation:

Insert the short leg (cathode / ground) of each LED into the square notched
pads on header P1, positions 4 and 7. These pads connect to ground through
1K current-limiting resistors. Insert the long leg (anode / positive) into
neighboring pads 3 and 8.

Leave enough lead length above the PCB so the LEDs can reach the enclosure
openings before soldering.

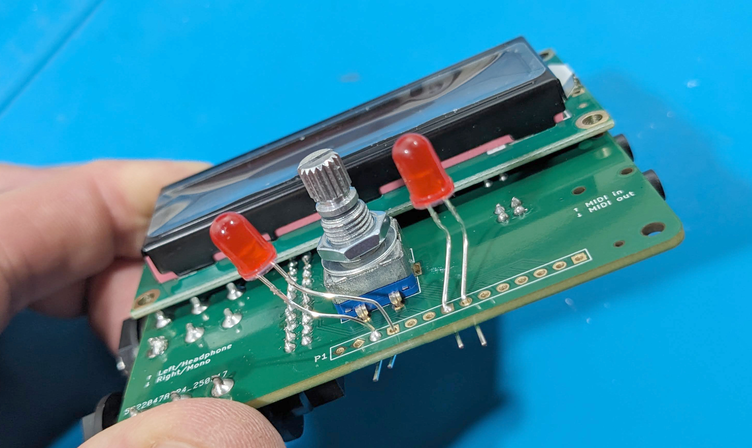
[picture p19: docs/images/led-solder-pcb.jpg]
LEDs sticking out of PCB

   
   Proper LED mounting

Footswitch Wiring:

Strip and tin four short wires (about 3 cm each).

Wire the switches as follows:

* Connect one lug of each switch to P1 pads 12 and 13 (GPIO9 and GPIO10)
* Connect P1 pad 14 (GND) to the remaining lug of one switch
* Bridge that grounded lug to the remaining lug of the second switch

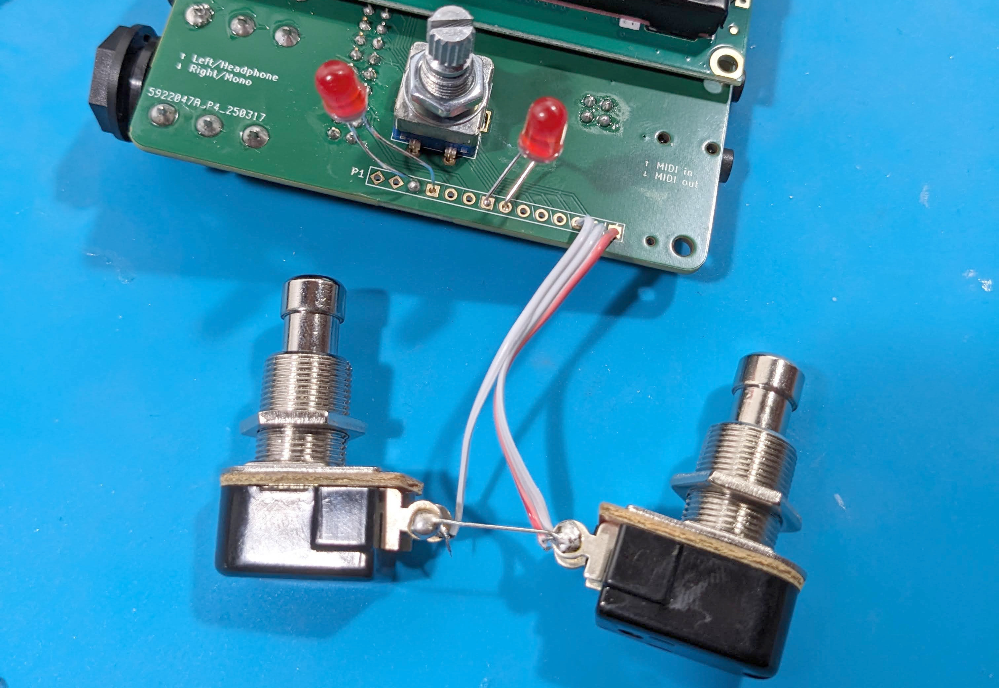
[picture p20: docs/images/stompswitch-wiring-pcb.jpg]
footswitches wired to PCB

   
   Footswitch wiring

Enclosure
---------

Align the rotary encoder shaft, LEDs (if installed), and audio jacks with the
corresponding enclosure openings.

Press the PCB into place and secure it using the washers and nuts supplied
with the rotary encoder and audio jacks. Mount stompswitches if used.

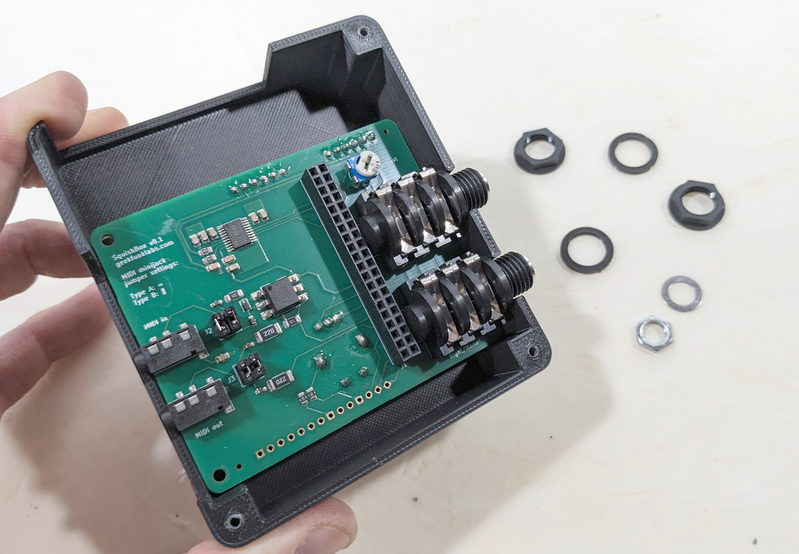
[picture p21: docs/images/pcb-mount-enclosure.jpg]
PCB mounted in 3D printed enclosure

   
   PCB mounted in enclosure

Install the Raspberry Pi by plugging its GPIO header into the 2x20 socket.

Secure the lid using the three included screws.

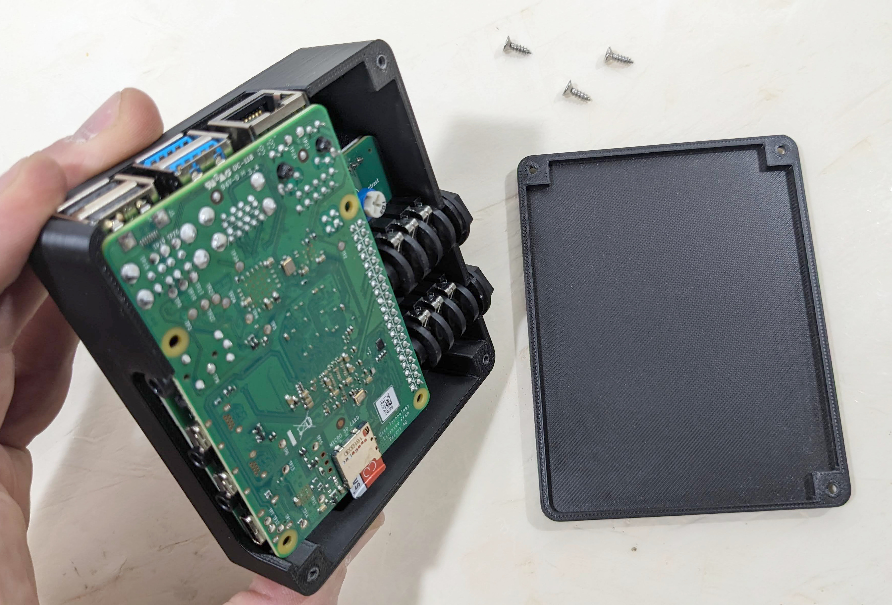
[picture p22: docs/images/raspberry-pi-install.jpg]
Raspberry Pi plugged into PCB

   
   Raspberry Pi Installation

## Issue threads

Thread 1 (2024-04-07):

Headless script error: Failed to add edge detection

insomniacUNDERSCORElemon, 2024-04-07:
```
Traceback (most recent call last):
  File "/home/anyusername/./squishbox.py", line 1100, in <module>
    sb = SquishBox()
  File "/home/anyusername/./squishbox.py", line 106, in __init__
    GPIO.add_event_detect(btn, GPIO.BOTH, callback=self._button_event)
RuntimeError: Failed to add edge detection
```
Raspberry Pi Model B Rev 2, as reported by software (revision 000e, some websites say this is revision 2.1, note: 2 USB ports and 512MB RAM)

OS: 2024-03-12-raspios-bullseye-armhf.img.xz (32-bit)

Audio output: headphone jack

Keyboard: Same as video (AKM322, uses midi channel 0 as expected though for some reason the codes are not the same)

This is after multiple attempts at installs (2nd clean install too, believe I had the same error the first time)

unRARed, 2024-04-10:
I think you're onto something. I received my v6 kit today, built it up and after booting a fresh image and running the install script, the display was sitting at the version number (`v6/0.8.5`) with no light on the led. Also, the switch and rotary were non-functioning. I found the [troubleshooting doc here](https://github.com/GeekFunkLabs/squishbox/blob/main/docs/troubleshooting.md) and running `./squishbox.py` produced the same error message:

```sh
squishbox:~ $ ./squishbox.py
Traceback (most recent call last):
  File "/home/mu_user/./squishbox.py", line 1071, in <module>
    sb = SquishBox()
         ^^^^^^^^^^^
  File "/home/my_user/./squishbox.py", line 122, in __init__
    GPIO.add_event_detect(btn, GPIO.BOTH, callback=self._button_event)
RuntimeError: Failed to add edge detection
```

I'm using the Raspberry Pi OS Lite 64bit per the official imager and `sndrpihifiberry` per the installation documentation.

unRARed, 2024-04-10:
On a hunch, I reloaded a fresh image of the prior Raspberry Pi OS (bullseye) and I didn't get this error. The led works as well as the button and rotary. However, no sound output yet.

insomniacUNDERSCORElemon, 2024-04-10:
A small note: I'm just using the Raspberry Pi on its own (no kit) and am thus not even using the GPIO. I mean maybe whatever that is could make a difference, but I feel like it shouldn't in my case (and even for the kit it should probably point this issue out during the install script).

albedozero, 2024-04-13:
Unfortunately, I've spent several days without success trying to replicate this error. I just did a small update that will prevent use of the GPIO when doing a "Naked Raspberry Pi" install, so that may at least solve @insomniacUNDERSCORElemon's issue.

@unRARed - I can tell by the line number that is producing the error that you're installing the "[legacy](https://github.com/albedozero/fluidpatcher)" version of the software, which might be what is causing your error. To install the current version, hosted in this repository, use the command

```bash
curl -sL geekfunklabs.com/squishbox | bash
```

unRARed, 2024-04-13:
@albedozero yes, I tried both versions of the installer script. I originally tried the latest RPI OS image and that's where I got the same error as OP and I shared the output. I should probably mention I used the "lite" images as I have never had any need for the desktop images on the PI. Retrying with the older, legacy Bullseye made it past this error, but I wasn't able to get audio working. I was able to get MIDI messages and the rotary, button and led all functioning though. Maybe I just wired the jacks wrong as I haven't tried any of the other audio output options to compare.

Can you try a fresh setup and confirm the specific image and settings you use to get to a working setup? I feel like the docs are a bit out of date; referring to legacy repos.

albedozero, 2024-04-14:
Ah, I've tried it with a Pi 4 running Bookworm and now I can reproduce the error. The culprit seems to be a recent change in the underlying way GPIO pins are accessed, as described in this very detailed article by [Dave Jones](https://waldorf.waveform.org.uk/2021/the-pins-they-are-a-changin.html). Seems like the change is slowly being integrated into different versions of the OS for different Pi's? I will have to do some more investigating to figure out the "right" way to fix this in the install script, but for now you can follow the suggestion from the lpgio library that you referenced:

```bash
sudo apt-get remove python3-rpi.gpio
sudo apt-get install python3-rpi-lgpio
```

This fixed the issue for me. Working on a general fix in #3. Also, you are correct that the documentation is a bit out of date #2 - this is WIP as well

insomniacUNDERSCORElemon, 2024-04-15:
> so that may at least solve your issue

Nope.

Fresh install (not sure if needed, but it failed with just an update too):

```
Traceback (most recent call last):
  File "/home/anyusername/./squishbox.py", line 1109, in <module>
    mainapp.load_bank(fp.currentbank)
  File "/home/anyusername/./squishbox.py", line 915, in load_bank
    sb.lcd_write(bank.name, 0, mode='scroll', now=True)
  File "/home/anyusername/./squishbox.py", line 249, in lcd_write
    if now: self.update(idle=0)
  File "/home/anyusername/./squishbox.py", line 175, in update
    if GPIO.input(b) == ACTIVE:
RuntimeError: You must setup() the GPIO channel first
Error in sys.excepthook:
Traceback (most recent call last):
  File "/home/anyusername/./squishbox.py", line 124, in <lambda>
    sys.excepthook = lambda etype, err, tb: self.display_error(err, etype=etype, tb=tb)
  File "/home/anyusername/./squishbox.py", line 537, in display_error
    self.waitfortap()
  File "/home/anyusername/./squishbox.py", line 308, in waitfortap
    if self.update(callback=False) != NULL:
  File "/home/anyusername/./squishbox.py", line 175, in update
    if GPIO.input(b) == ACTIVE:
RuntimeError: You must setup() the GPIO channel first

Original exception was:
Traceback (most recent call last):
  File "/home/anyusername/./squishbox.py", line 1109, in <module>
    mainapp.load_bank(fp.currentbank)
  File "/home/anyusername/./squishbox.py", line 915, in load_bank
    sb.lcd_write(bank.name, 0, mode='scroll', now=True)
  File "/home/anyusername/./squishbox.py", line 249, in lcd_write
    if now: self.update(idle=0)
  File "/home/anyusername/./squishbox.py", line 175, in update
    if GPIO.input(b) == ACTIVE:
RuntimeError: You must setup() the GPIO channel first
```

albedozero, 2024-04-15:
Oops, I missed a GPIO.input. Try updating again now (you shouldn't need to do a fresh install).

It seems that the python3-rpi-lgpio package is only available in Raspberry Pi OS bookworm, and it's not needed for bullseye. You can check what Raspberry Pi OS version you have with `cat /etc/os-release`.

insomniacUNDERSCORElemon, 2024-04-15:
> Try updating again now (you shouldn't need to do a fresh install)

I'm not sure what happened, I ran it again and it didn't take.
I manually edited the change it and now it works, thank you.

Not sure my Pi fast enough for it, though...  it didn't take long to crash, and sound is choppy most of the time.

albedozero, 2024-04-16:
@insomniacUNDERSCORElemon if I understand correctly that you're using a Raspberry Pi 2B, that would explain your audio issues. I consider the Pi 3B+ to be the baseline model for the synth to work smoothly. I notice some latency on a Pi 3B. I used to have a Pi 2 available, and sound was pretty choppy. You can improve this by increasing audio.period-size and audio.periods in the SquishBox/fluidpatcherconf.yaml file, but at the cost of audio latency.

insomniacUNDERSCORElemon, 2024-04-16:
> you can improve this by increasing audio.period-size and audio.periods in the SquishBox/fluidpatcherconf.yaml file, but at the cost of audio latency

I'm not sure this is the issue. A single note can play just fine. Playing at a moderate pace or multiple notes is where it gets choppy, like the CPU is not fast enough to process it (and keeping at it causes it to crash). Probably depends on the sound font too.

unRARed, 2024-04-19:
I realize there's multiple issues in this thread, so maybe this should be its own issue, but my latest attempt was installing on my older Pi 3B on the "recommended" 32bit image. The OS and script installed without issue and booted directly to the interface. Both the Rotary, Button and LED also seem to function flawlessly, but there's still no sound out of the 1/4" jacks. I tried disabling all the other sound devices, too.

Is it possible the script is assuming the user is `pi`? In all cases, I've preconfigured the Pi image with a custom username and password, but I've confirmed my user is in the audio group.

The closest thing I've achieved sound-wise is plugging in a little pocket guitar amp. There's a noise on the line until I run `./squishbox.py`. At this point the noise is gone. When I terminate the process, the noise returns. Is it possible the wiring diagram is wrong in the installation PDF for the 1/4" jacks?

albedozero, 2024-04-25:
fixed by #3

Closed 2024-04-25.

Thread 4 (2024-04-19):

Audio muted on 1/4" jacks, LCD and buttons are working

albedozero, 2024-04-19:
_Originally posted by @unRARed in https://github.com/GeekFunkLabs/squishbox/issues/1#issuecomment-2067041318_

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

albedozero, 2024-04-19:
I don't think the issue could be installing with a user other that `pi` - I've tested this many times with no issues. I think the quickest way to isolate whether it's a wiring problem would be to connect some headphones to the Pi's on-board audio jack and change the following line in SquishBox/fluidpatcherconf.yaml:

```yaml
  audio.alsa.device: sndrpihifiberry
```

to

```yaml
  audio.alsa.device: Headphones
```

The wiring guide in the latest documentation, [linked from this repo](https://geekfunklabs.github.io/squishbox/assembly.html#hardware), is correct.

albedozero, 2024-05-19:
Any developments on this issue @unRARed?

unRARed, 2024-05-19:
I’m slammed with projects lately so unfortunately no, I haven’t had a chance to. I double checked the wiring, and I can’t see an issue there though. You can privately close this for now. Not sure when I’ll be able to revisit. Thanks for the support!

Closed 2024-06-25.

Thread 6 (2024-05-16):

Fluidsynth: Failed to set thread to high priority

cpu150, 2024-05-16:
# Description
After a fresh install and reboot the service starts with the log `fluidsynth: warning: Failed to set thread to high priority`

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

# Steps to reproduce
1. Flash `Raspberry Pi Os Lite (64-bit)` (Debian Bookworm - no desktop environment)
2. Update system: `sudo apt update ; sudo apt -y upgrade`
3. Install SquishBox as `Naked Raspberry Pi Synth`
4. Reboot
5. Watch status: `systemctl status squishbox`

Result: The log `fluidsynth: warning: Failed to set thread to high priority` appears
Expected: No failure

# Setup
Raspberry Pi Zero 2W:
- Operating System: Debian GNU/Linux 12 (bookworm)
- Kernel: Linux 6.6.28+rpt-rpi-v8
- Architecture: arm64

Squishbox:
- Naked Raspberry Pi Synth
- USB audio output - card 0: Audio [Hi-Res Audio], device 0: USB Audio [USB Audio]

cpu150, 2024-05-16:
# Proposed fix
Give the service the right to change the thread priority by adding in `squishbox-install.bash` script under the `[Service]` section:
`LimitMEMLOCK=infinity
LimitRTPRIO=90`

@albedozero I have a local branch with the fix but can't push it (I don't have the rights). I can push it and create a pull request if it helps

albedozero, 2024-05-19:
Fantastic. I'd thought this was unfixable and the warnings just had to be ignored, but this solves it and is [corroborated in the forums](https://forums.raspberrypi.com/viewtopic.php?t=211327) as well. I'd be happy to merge a pull request but this one was quick so I just did it with #8. Thanks for contributing!

Closed 2024-05-19.

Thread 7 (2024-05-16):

Web-based file manager - Root path not found

cpu150, 2024-05-16:
# Description
After a fresh install and reboot I got an error while trying to access the web-based file manager.
After logging in this error message is shown: `Root path "/home/cpu150/SquishBox" not found!`

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

# Steps to reproduce
1. Flash `Raspberry Pi Os Lite (64-bit)` (Debian Bookworm - no desktop environment) image
2. Update system: `sudo apt update ; sudo apt -y upgrade`
3. Install SquishBox as `Naked Raspberry Pi Synth`
4. Reboot
5. Access the Web-based file manager from a web browser
6. Log in

Result: Get a not found error message
Expected: Should display the Squishbox root folder content

# Setup
Raspberry Pi Zero 2W:
- Operating System: Debian GNU/Linux 12 (bookworm)
- Kernel: Linux 6.6.28+rpt-rpi-v8
- Architecture: arm64

Squishbox:
- Naked Raspberry Pi Synth
- USB audio output - card 0: Audio [Hi-Res Audio], device 0: USB Audio [USB Audio]

cpu150, 2024-05-16:
It seems to be a rights issue:
My home directory is set as: `drwx------  4 cpu150 cpu150 4096 May 16 15:24 cpu150`
If I change as `chmod 750 ~`:  `drwxr-x---  4 cpu150 cpu150 4096 May 16 15:24 cpu150`
then it works fine.
Which makes sense `nginx` server is ran by `www-data` user.

The above allows us to confirm where the issue comes from however I would not recommend that as a solution as it introduces security issues.
I don't have a proper solution for that.
Maybe changing the default installation folder?

albedozero, 2024-05-19:
Debian 12 Bookworm (or at least the Raspberry Pi OS version of it) causes this problem by using default permissions 700 (`drwx------`) for home directories. Up until Bullseye it was 755 (`drwxr-xr-x`), which works fine as long as `www-data` is added to the user's group.

I think the solution is to make sure directories in the path to `SquishBox/`, wherever it is installed, are group-executable (i.e. `drwx--x---`). That way `www-data` can traverse them but not write anywhere it isn't supposed to. Alternate default locations might be `/usr/local/share/SquishBox` or `/srv/SquishBox`, but those will require permission/ownership changes as well, and I feel like the home directory is the easiest place for users to find bank and config files if they log into the Pi.

cpu150, 2024-05-19:
Indeed: I just tried to give just the executable right and it sounds working fine (`drwx--x---`).
I got your point and do agree: it's easier to find if in the home directory.
Maybe a symbolic link could be a work around?

Also (but this connects with another big topic so happy to have it somewhere else than here), I have seen another project with the system in read only which makes it easier to shutdown (no way to corrupt a file so no need a command to power it off).
If this sounds interesting to you then I would suggest to create another partition (rw) and install `SquishBox` files there while keeping the system partition as read only.

albedozero, 2024-05-19:
fixed by #9

Closed 2024-05-19.

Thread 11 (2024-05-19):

Make read-only filesystem an option for easier shutdown

albedozero, 2024-05-19:
Also (but this connects with another big topic so happy to have it somewhere else than here), I have seen another project with the system in read only which makes it easier to shutdown (no way to corrupt a file so no need a command to power it off).
If this sounds interesting to you then I would suggest to create another partition (rw) and install `SquishBox` files there while keeping the system partition as read only.

_Originally posted by @cpu150 in https://github.com/GeekFunkLabs/squishbox/issues/7#issuecomment-2119235838_

albedozero, 2024-05-19:
Locking up the user's file system is a bit too drastic I think. My philosophy is that the Pi is a computer, so if you want to unplug it without shutting down properly you accept the risks. In practice you _can_ just unplug it most of the time with no ill effects - as long as the SD card isn't being written, which is indicated by the green LED and only happens when loading or saving a bank, there's little chance of corruption.

This is suggested/requested often, so maybe it's worth putting the procedure in the user manual as an option for power users. I'm planning some updates/revisions to the manual anyway (see #2)

cpu150, 2024-05-29:
@albedozero I am documenting what I did in case it could help.

The command to boot the system as read only: `sudo raspi-config nonint do_overlayfs 0`
(you revert with: `sudo raspi-config nonint do_overlayfs 1`)
Reboot to apply the change: `sudo reboot`

As the project is today it seems working fine as soon as there is no bank change. (Probably because `fluidpatcher` tries to write the config)

This is where it starts to get tricky.
To solve this issue you could install `SquishBox` RW partition, which could be a USB key.
This is the most straightforward solution I can think about but I guess it misses the point of the project which tend to have something small and all in a box.

The solution I came across (more portable than the above one but more complicated) is to create another partition on the SD card.
I am running `Bookworm` distrib.
During the first boot the Raspberry Pi will resize the root partition to make it fill entirely the SD card size.
I did not find a way to avoid that so I had to shrink back the root partition.
I have looked at resizing the root partition while the system is running but did not have luck.
I found that I can use `initramfs` to resize the partition before the root partition get mounted (I think this what it is used to expand the root partition at the first boot).
I tried few things unfortunately I never got it running while booting...
So I got another Linux and plugged the SD card as USB key.

Some useful commands:
  `uname -r` - Prints the kernel release (useful if while using `initramfs`)
  `df -h`    - Checks disk usage

WARNING: The following could end up by loosing everything if it fails. It worth backing up everything before.
Shrink the root partition:
  1. Get partition using `lsblk` (in my case the SD card is `/dev/sda` and the partition I want to resize is `/dev/sda2`)
  2. Clean filesystem up: `sudo e2fsck -yf /dev/sda2`
  3. Resize filesystem: `sudo resize2fs /dev/sda2 6G` (in my case I shrink it down to 6 GB)
      If getting this message: `resize2fs: New size smaller than minimum (1616971)`
      Then it means it is too small
  4. List details of each partitions using `sudo parted /dev/sda print`
      Output example:
        Number  Start   End     Size    Type     File system  Flags
         1      4194kB  541MB   537MB   primary  fat32        lba
         2      541MB   62.3GB  61.7GB  primary  ext4
  5. Resize partition: `sudo parted /dev/sda resizepart 2 6541MB`
      `2` is the partition number
      `6542MB` is where I want the partition to end:
        Start of the partition (in this case 541MB) + size I want (in my case 6GB == 6000MB) + 1MB
  6. Clean it up again: `sudo e2fsck -f /dev/sda2`
      I got asked: `Abort<y>?`
      I answered `no`
      When I got asked one of theses:
        `Ignore error<y>?`
        `Force rewrite<y>?`
        `Fix<y>?`
      It failed for me. (not booting anymore)
  7. And finally: `sudo resize2fs -f /dev/sda2`

If you are going with the `initramfs` solution then you want to execute the steps `2` and `3` in your `initramfs` script.

Create a new partition: (I want another 6GB == 6000MB partition)
  1. `sudo parted /dev/sda mkpart p ext4 6542MB 12542MB`
      `6542MB`  End of Prev Partition
      `12542MB` End of partition: Start (6542MB) + 6000MB
  2. Format partition as `ext4` `sudo mkfs.ext4 /dev/sda3`
  3. Boot on the SD card
  4. `mkdir ~/rw_disk`
  5. Get the new partition using `lsblk` (in my case /dev/mmcblk0p3)
  6. Edit `/etc/fstab` and add: `/dev/mmcblk0p3  /home/pi/rw_disk  ext4    defaults,noatime  0       0`
      Change `/dev/mmcblk0p3` and `/home/pi/rw_disk` as per your setup
  7. `sudo reboot`
  8. `sudo mkdir ~/rw_disk/SquishBox` and `sudo chown pi:pi -R ~/rw_disk/SquishBox`
  9. Install `SquishBox` to `~/rw_disk/SquishBox` directory
  10. Setup the system as read only: `sudo raspi-config nonint do_overlayfs 0`
  11. `sudo reboot`

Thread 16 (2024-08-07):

No sound produced

Pauldb8, 2024-08-07:
Hello,

First off thank you for this great idea ! I have a M-AUDIO OxygenPro61 and wanted to use it standalone to play and sing along.
I have a RPi that is currently being used for Pi-hole (DNS with adblock) pretty light and stays at 0.00 load all the time.

Now I've updated my RPi (had been a while) and ran the script via the recommended command (curl xxx | bash).
Now the services seems to start fine.

I'm using Raspbian, kernel: 6.1.21-v7+

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

However no sound is produced.

- The keyboard does light up and I know it works when using it on Linux on another machine
- The jack does produce sound (using headphone I tested with aplay somewavefile.wav and did hear sound)
- no errors in the logs
- says it's connected to Oxygen Pro 61 (but there are many in the list maybe it's this ?)
- tried restarting multiple times

Now I'm out of idea, but I'd like to make it work because it would be so nice !

Thank you for your help.

albedozero, 2024-08-07:
Seems like it could be a problem with the multiple MIDI devices - maybe they're assigned to channels other than the one set in the bank file. Enter this command to see what the port numbers are:

```bash
aconnect -iol
```

Then, you can see what MIDI messages are being sent by each of the devices your OxygenPro is presenting by entering

```bash
aseqdump -p<port>
```

Where you change `<port>` to one of the client numbers given by `aconnect`. Let me know what you find and I can help troubleshoot.

Pauldb8, 2024-08-08:
Hey thank you for the feedback !
Indeed by setting `MIDI_CTRL = 0` in the `squishbox.py` file, it now works !
This is very cool :) and exactly what I needed !

I also have a question, how might I get to know which of my buttons correspond to which number ?
So as to be able to change Banks and sounds ? The default don't work.

Another feedback, by installing the web file uploader, the service wouldn't start because it needed "nmcli":
````
aoû 07 17:22:22 raspberrypi systemd[1]: Started SquishBox.
aoû 07 17:22:25 raspberrypi squishbox.py[489]: /bin/sh: 1: nmcli: not found
aoû 07 17:22:26 raspberrypi squishbox.py[379]: Traceback (most recent call last):
aoû 07 17:22:26 raspberrypi squishbox.py[379]:   File "/home/pi/squishbox.py", line 1101, in <module>
aoû 07 17:22:26 raspberrypi squishbox.py[379]:     sb = SquishBox()
aoû 07 17:22:26 raspberrypi squishbox.py[379]:   File "/home/pi/squishbox.py", line 123, in __init__
aoû 07 17:22:26 raspberrypi squishbox.py[379]:     self.wifi_state()
aoû 07 17:22:26 raspberrypi squishbox.py[379]:   File "/home/pi/squishbox.py", line 589, in wifi_state
aoû 07 17:22:26 raspberrypi squishbox.py[379]:     state = 'on' if self.shell_cmd("nmcli radio wifi") == 'enabled' else 'off'
aoû 07 17:22:26 raspberrypi squishbox.py[379]:   File "/home/pi/squishbox.py", line 553, in shell_cmd
aoû 07 17:22:26 raspberrypi squishbox.py[379]:     return subprocess.run(cmd, check=True, stdout=subprocess.PIPE, shell=True,
aoû 07 17:22:26 raspberrypi squishbox.py[379]:   File "/usr/lib/python3.9/subprocess.py", line 528, in run
aoû 07 17:22:26 raspberrypi squishbox.py[379]:     raise CalledProcessError(retcode, process.args,
aoû 07 17:22:26 raspberrypi squishbox.py[379]: subprocess.CalledProcessError: Command 'nmcli radio wifi' returned non-zero exit status 127.
aoû 07 17:22:26 raspberrypi systemd[1]: squishbox.service: Main process exited, code=exited, status=1/FAILURE
aoû 07 17:22:26 raspberrypi systemd[1]: squishbox.service: Failed with result 'exit-code'.
aoû 07 17:22:26 raspberrypi systemd[1]: squishbox.service: Consumed 1.387s CPU time.
aoû 07 17:22:26 raspberrypi systemd[1]: squishbox.service: Scheduled restart job, restart counter is at 1.
aoû 07 17:22:26 raspberrypi systemd[1]: Stopped SquishBox.
aoû 07 17:22:26 raspberrypi systemd[1]: squishbox.service: Consumed 1.387s CPU time.
```

Keep in mind my RPi originally is Raspbian with Pi-Hole (DNS adblocker for my home, and as it happens DCHP too).

I fixed by installing network-manager. It then started.
But then when I restarted my RPI. My whole network broke..
Because my RPi is used a DCHP server (giving IPs to everyone), but network-manager took over the `/etc/dhcpcd.conf` (static IP for the PI), and then it wouldn't get an IPv4 address anymore, and other devices couldn't find RPi.
Which drove me crazy.
Solution was using network-manager utility to set the same  IP/DNS/Subnet configuration as in the `/etc/dhcpcd.conf` file, by typing: `sudo nmtui` and visually configuring.

Then after a restart everything now works as expected on startup. Phew !
Thank you.

Closed 2024-08-16.

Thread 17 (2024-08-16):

Cannot change patches using MIDI controls

albedozero, 2024-08-16:
I also have a question, how might I get to know which of my buttons correspond to which number ?
So as to be able to change Banks and sounds ? The default don't work.

albedozero, 2024-08-16:
The simplest way is to configure a couple of the pads/buttons on your controller to send momentary CC messages 21 and 22 on MIDI channel 1. Otherwise, you can modify the values of MIDI_CTRL, MIDI_INC, and MIDI_DEC [here](https://github.com/GeekFunkLabs/squishbox/blob/410a8fe07ae3611b6d22c197434bf9f069066e84/squishbox.py#L52) in the squishbox.py file.

luucvanderzee, 2024-08-18:
Hello, sorry if this is a stupid question, I am new to midi and raspberry PI... but I can't get the patch change controls to work.

I have an Arturia Minilab 3 connected to my raspberry PI. Using the normal keys works, but I want to use some of the fingerdrum pads of the controller for the patch selection. I ran `aseqdump -p 20:0` on my PI  to read what midi channels and notes my pads are- it turns out they are notes 41-43 on channel 9. I then changes the variables in the `squishbox.py` channel in the following way:

```
MIDI_CTRL = 9
MIDI_DEC = 41
MIDI_INC = 42
MIDI_PATCH = 43
```

and rebooted the PI, but it doesn't work- using the pads doesn't change the patch. What am I missing / misunderstanding here?

albedozero, 2024-08-18:
@luucvanderzee it seems likely that your pads are sending notes instead of control change (CC) messages. You can change this in your MIDI controller, or in the [add_midicontrols](https://github.com/GeekFunkLabs/squishbox/blob/410a8fe07ae3611b6d22c197434bf9f069066e84/squishbox.py#L1074) function change the `type` arguments to `cc`.

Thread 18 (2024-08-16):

Installation breaks network connections

albedozero, 2024-08-16:
Another feedback, by installing the web file uploader, the service wouldn't start because it needed "nmcli":
```
aoû 07 17:22:22 raspberrypi systemd[1]: Started SquishBox.
aoû 07 17:22:25 raspberrypi squishbox.py[489]: /bin/sh: 1: nmcli: not found
aoû 07 17:22:26 raspberrypi squishbox.py[379]: Traceback (most recent call last):
aoû 07 17:22:26 raspberrypi squishbox.py[379]:   File "/home/pi/squishbox.py", line 1101, in <module>
aoû 07 17:22:26 raspberrypi squishbox.py[379]:     sb = SquishBox()
aoû 07 17:22:26 raspberrypi squishbox.py[379]:   File "/home/pi/squishbox.py", line 123, in __init__
aoû 07 17:22:26 raspberrypi squishbox.py[379]:     self.wifi_state()
aoû 07 17:22:26 raspberrypi squishbox.py[379]:   File "/home/pi/squishbox.py", line 589, in wifi_state
aoû 07 17:22:26 raspberrypi squishbox.py[379]:     state = 'on' if self.shell_cmd("nmcli radio wifi") == 'enabled' else 'off'
aoû 07 17:22:26 raspberrypi squishbox.py[379]:   File "/home/pi/squishbox.py", line 553, in shell_cmd
aoû 07 17:22:26 raspberrypi squishbox.py[379]:     return subprocess.run(cmd, check=True, stdout=subprocess.PIPE, shell=True,
aoû 07 17:22:26 raspberrypi squishbox.py[379]:   File "/usr/lib/python3.9/subprocess.py", line 528, in run
aoû 07 17:22:26 raspberrypi squishbox.py[379]:     raise CalledProcessError(retcode, process.args,
aoû 07 17:22:26 raspberrypi squishbox.py[379]: subprocess.CalledProcessError: Command 'nmcli radio wifi' returned non-zero exit status 127.
aoû 07 17:22:26 raspberrypi systemd[1]: squishbox.service: Main process exited, code=exited, status=1/FAILURE
aoû 07 17:22:26 raspberrypi systemd[1]: squishbox.service: Failed with result 'exit-code'.
aoû 07 17:22:26 raspberrypi systemd[1]: squishbox.service: Consumed 1.387s CPU time.
aoû 07 17:22:26 raspberrypi systemd[1]: squishbox.service: Scheduled restart job, restart counter is at 1.
aoû 07 17:22:26 raspberrypi systemd[1]: Stopped SquishBox.
aoû 07 17:22:26 raspberrypi systemd[1]: squishbox.service: Consumed 1.387s CPU time.
```

Keep in mind my RPi originally is Raspbian with Pi-Hole (DNS adblocker for my home, and as it happens DCHP too).

I fixed by installing network-manager. It then started.
But then when I restarted my RPI. My whole network broke..
Because my RPi is used a DCHP server (giving IPs to everyone), but network-manager took over the `/etc/dhcpcd.conf` (static IP for the PI), and then it wouldn't get an IPv4 address anymore, and other devices couldn't find RPi.
Which drove me crazy.
Solution was using network-manager utility to set the same  IP/DNS/Subnet configuration as in the `/etc/dhcpcd.conf` file, by typing: `sudo nmtui` and visually configuring.

Then after a restart everything now works as expected on startup. Phew !
Thank you.

_Originally posted by @Pauldb8 in https://github.com/GeekFunkLabs/squishbox/issues/16#issuecomment-2275084678_

albedozero, 2024-08-16:
Thanks for noticing this. The installer script installs `network-manager` so that a user can turn the wifi on/off with the SquishBox. If you're not already using networkmanager that breaks your config. This little shell-script installer can't handle every possible configuration a user might already have on their Pi, but I will add a warning in the installer, (or maybe just skip it for the naked Pi synth) since that has a high potential to break things.

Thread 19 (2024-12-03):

No Audio from Patches???

nickbungus, 2024-12-03:
Hi - let me start by saying that this looks an awesome project and I'm sure the issue is down to me being dumb rather than anything else.

So I have built a Squishbox with the following:

- Raspberry Pi 3B+
- Raspberry PI OS Lite (64-bit)
- 16x2 LCD Screen
- PCM5102 DAC module
- v2 Squishbox Install

I'm using an M-Audio Keystation61 Mk3 midi controller, I have set Midi Channel 1 for controls and note info is on channel 16.  I've modified the squishbox.py script setting MIDI_CTRL  = 1 and then mapped MIDI_DEC, MIDI_INC, MIDI_SELECT and MIDI_ESCAPE to the Direction and Transport Buttons on the Keystation.  Going forward I will add a rotary encoder and a button when I'm ready to put it in an enclosure.

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

The control seems to be working fine but I'll get to that in a moment.

So when I start up Squishbox, I get the loading screen and then it loads the Patch Bank etc.  So after about 10 seconds I get Piano Patch 1/12.  Everything looks great until I press some keys and get nothing.  The LCD screen displays a Note symbol so recognizes input.

This is where is gets confusing, on the image above where the big number 2 is are the +/- Octave buttons, I've mapped these on my Keystation to +/- **Program**(ie, its going to send a midi message to Inc and Dec the Program).  If I press one of these and then press a note key I do get sound.  By pressing the Program +/-, it appears as though I'm going through all the sounds of the loaded Soundfont.  This doesnt seem to relate to the LCD screen as theres a lot more than 12 sounds and the LCD screen still says piano.

If I then press my MIDI_DEC or MIDI_INC mapped keys, the patch will change on the LCD screen, but I have no sound when pressing keys.  If I then press one of the +/- Octave(Program) buttons, I then have sound again and can again loop through the soundfont sounds.

To make it easier to understand, heres a quick Youtube video:
[https://youtube.com/shorts/bayCLKXEWUc](url)

Please help?  Any suggestions as to whats going wrong?  I think the patches arent loading properly but when I press the Octave/Program buttons, its talking to FluidSynth directly and changing the sounds of the loaded Soundfont - just a theory though.

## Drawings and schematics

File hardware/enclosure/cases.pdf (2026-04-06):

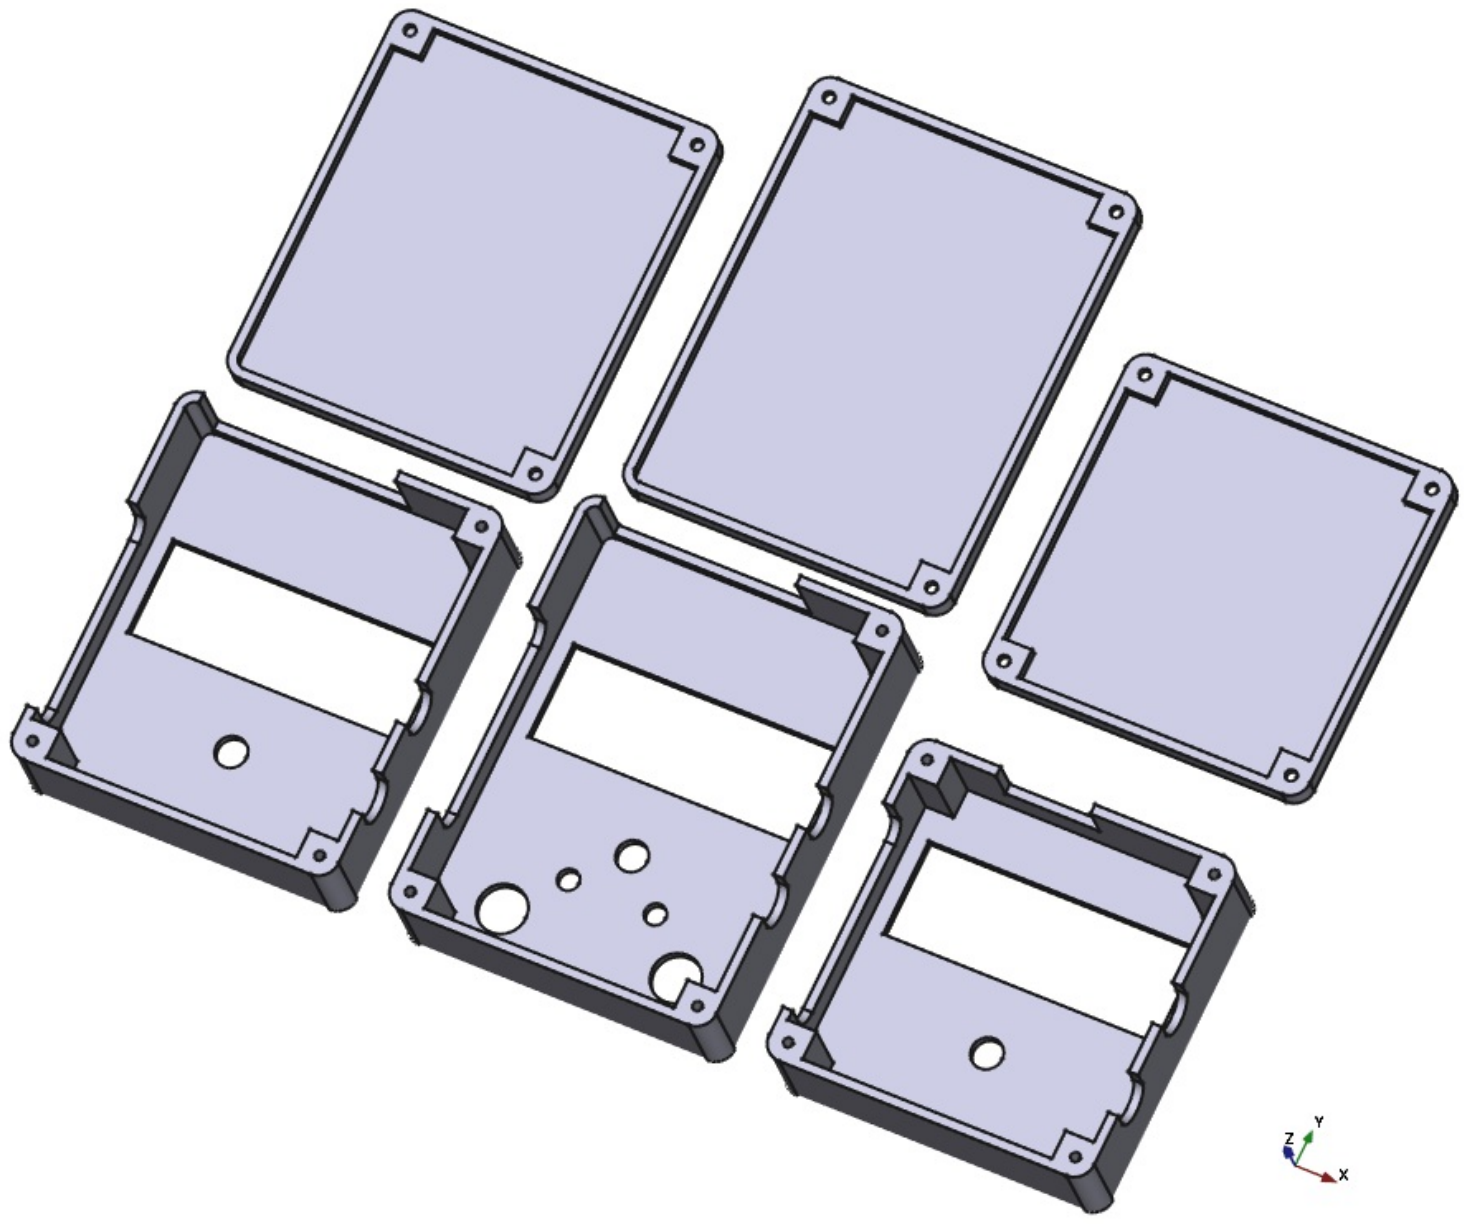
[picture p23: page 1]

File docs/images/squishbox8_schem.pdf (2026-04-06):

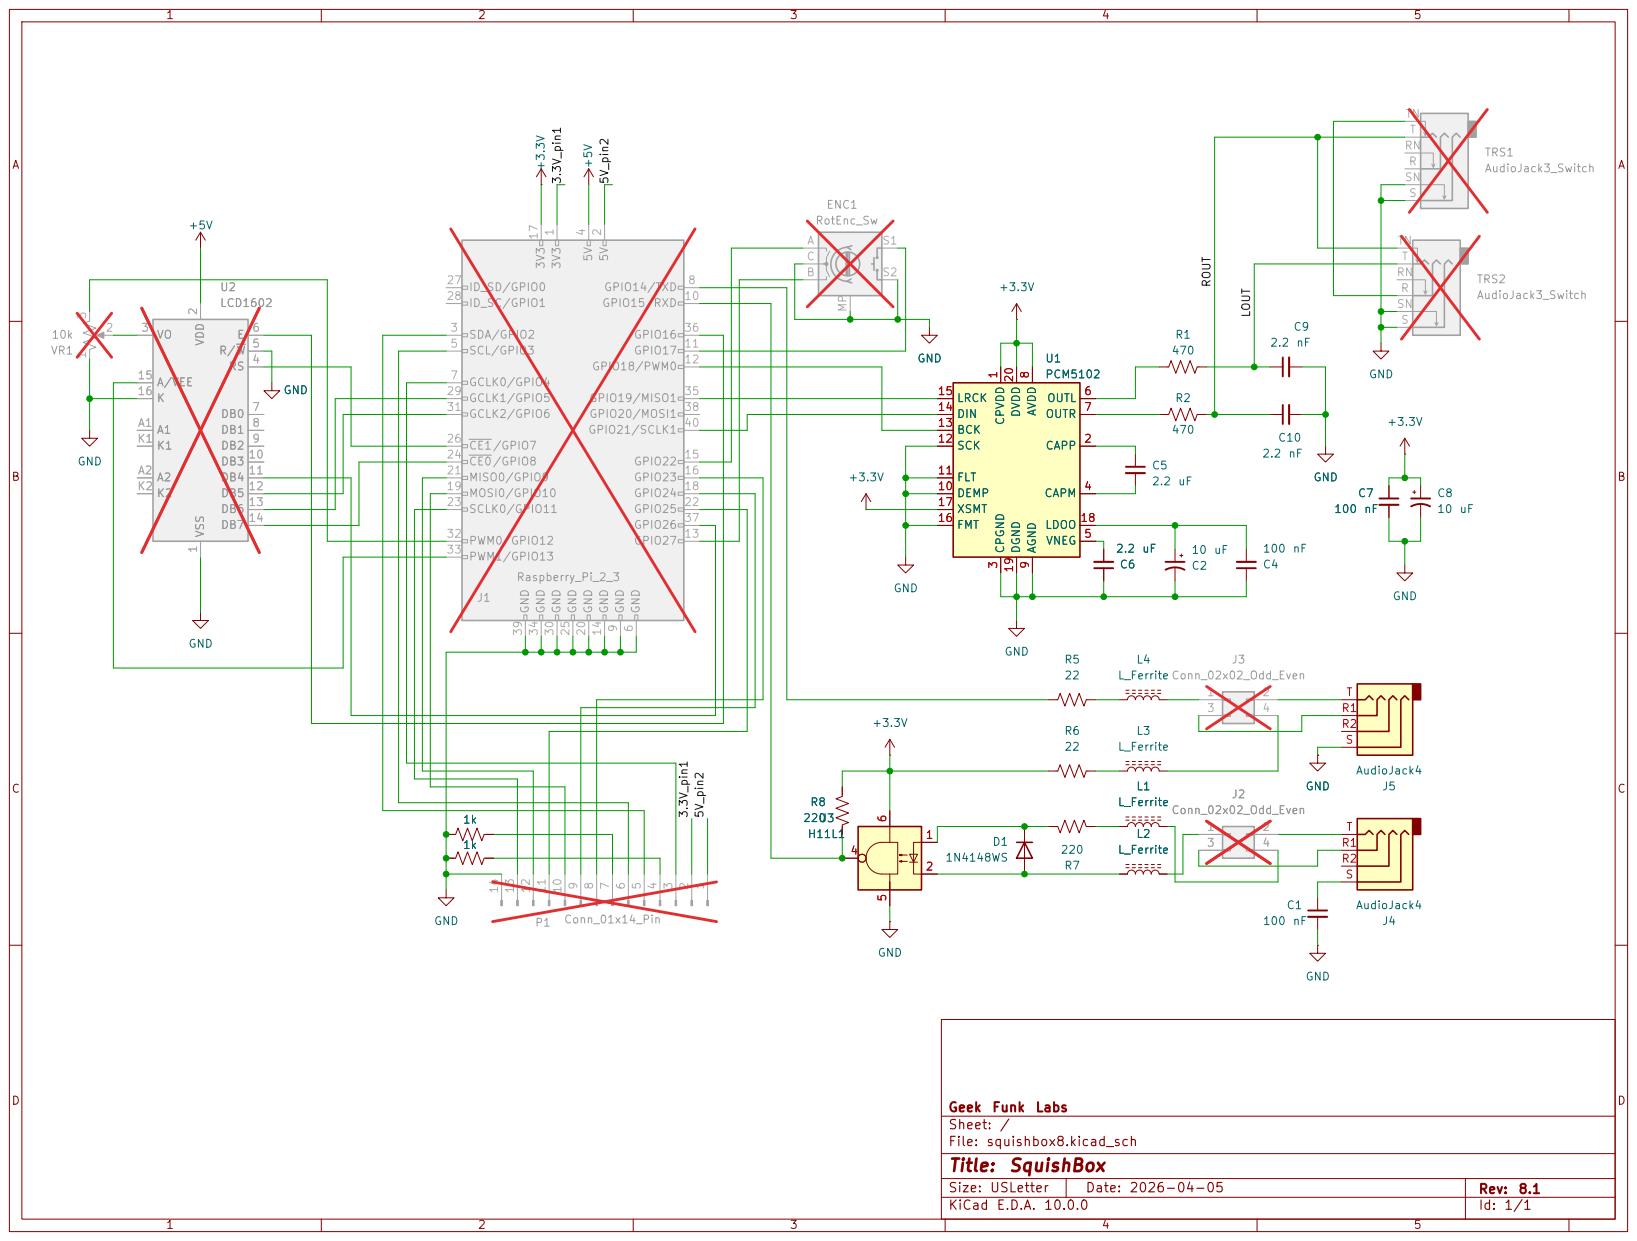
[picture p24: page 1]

Size: USLetter | Rev: 8.1

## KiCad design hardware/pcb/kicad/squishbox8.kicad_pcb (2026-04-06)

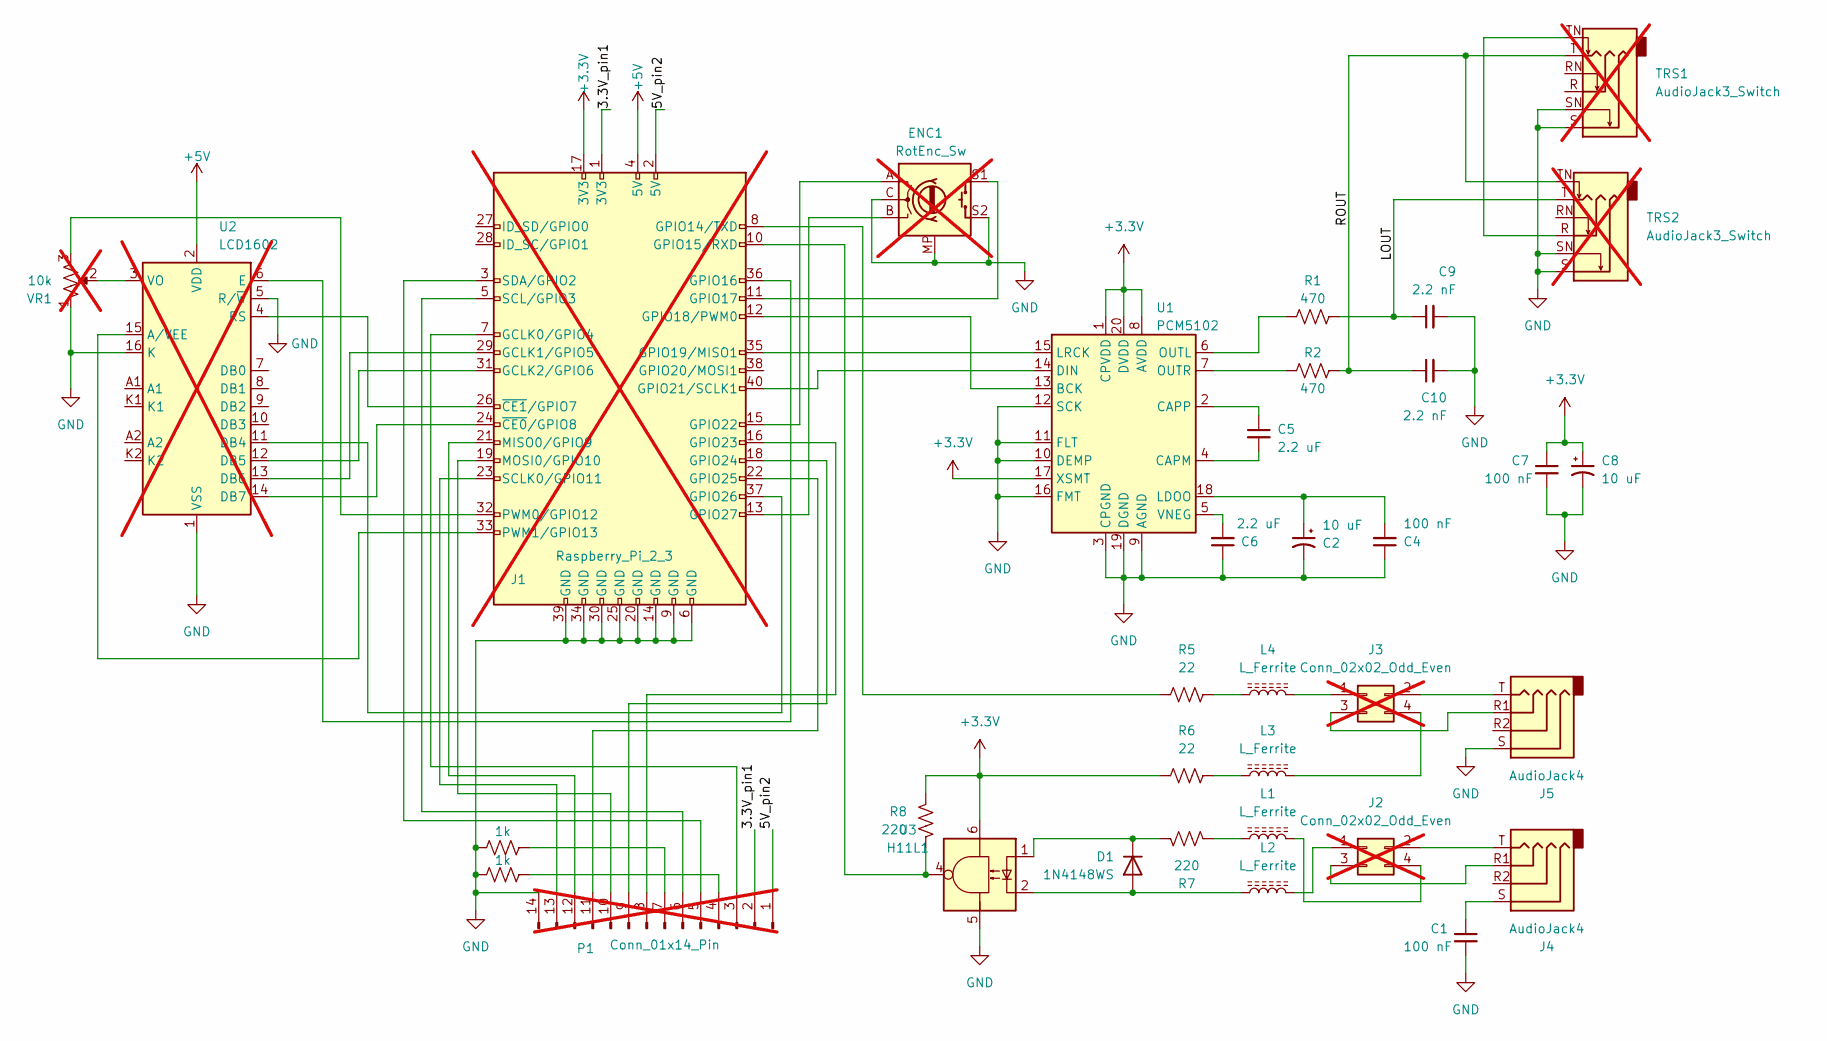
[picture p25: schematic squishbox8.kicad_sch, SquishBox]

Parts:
C1, C4, C7: 100 nF; C_0805_2012Metric; MPN 0805F104M500NT; LCSC C28378
C2, C8: 10 uF; C_0805_2012Metric; MPN 0805B106K100NT; LCSC C90544
C5, C6: 2.2 uF; C_0805_2012Metric; MPN 0805B225K250NT; LCSC C74690
C9, C10: 2.2 nF; C_0805_2012Metric; MPN 0805B222K101NT; LCSC C49956
D1: 1N4148WS; D_SOD-323; MPN 1N4148WS; LCSC C2128
ENC1: RotEnc_Sw; RotaryEncoder_Alps_EC11E-Switch_Vertical_H20mm; not fitted
J1: Raspberry_Pi_2_3; PinSocket_2x20_P2.54mm_Vertical; not fitted
J2, J3: Conn_02x02_Odd_Even; PinHeader_2x02_P2.54mm_Vertical; not fitted
J4, J5: AudioJack4; Jack_3.5mm_KoreanHropartsElec_PJ-320D-4A_Horizontal; MPN PJ-320D; LCSC C431535
L1, L2, L3, L4: L_Ferrite; L_0603_1608Metric; MPN GZ1608D601TF; LCSC C1002
P1: Conn_01x14_Pin; PinHeader_1x14_P2.54mm_Vertical; not fitted
R1, R2: 470; R_0805_2012Metric; MPN RS-05K471JT; LCSC C119076
R3, R4: 1k; R_0805_2012Metric; MPN ARG05FTC1001; LCSC C218388
R5, R6: 22; R_2010_5025Metric; MPN FRC2010J220TS; LCSC C3000647
R7, R8: 220; R_1206_3216Metric; MPN 1206W4J0221T5E; LCSC C25363
TRS1, TRS2: AudioJack3_Switch; Jack_6.35mm_Neutrik_NMJ6HFD4_Horizontal; not fitted
U1: PCM5102; TSSOP-20_4.4x6.5mm_P0.65mm; MPN PCM5102APWR; LCSC C107671
U2: LCD1602; PinSocket_1x16_P2.54mm_Vertical; not fitted
U3: H11L1; SMDIP-6_W9.53mm; MPN H11L1S(TA); LCSC C78589
VR1: 10k; Potentiometer_Piher_PT-6-V_Vertical; not fitted

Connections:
+3.3V: C7.1, C8.1, J1.17 (3V3), R6.1, R8.1, U1.1 (CPVDD), U1.8 (AVDD), U1.17 (XSMT), U1.20 (DVDD), U3.6
+5V: J1.4 (5V), U2.2 (VDD)
/3.3V_pin1: J1.1 (3V3), P1.2
/5V_pin2: J1.2 (5V), P1.1
/LOUT: C9.1, R1.2, TRS2.T
/ROUT: C10.1, R2.2, TRS1.T, TRS2.TN
GND: C1.2, C2.2, C4.1, C6.1, C7.2, C8.2, C9.2, C10.2, ENC1.C, ENC1.MP, ENC1.S2, J1.6 (GND), J1.9 (GND), J1.14 (GND), J1.20 (GND), J1.25 (GND), J1.30 (GND), J1.34 (GND), J1.39 (GND), J5.S, P1.14, R3.2, R4.2, TRS1.S, TRS1.SN, TRS2.S, TRS2.SN, U1.3 (CPGND), U1.9 (AGND), U1.10 (DEMP), U1.11 (FLT), U1.12 (SCK), U1.16 (FMT), U1.19 (DGND), U2.1 (VSS), U2.5 (R/~W), U2.16 (K), U3.5, VR1.1
unnamed: C1.1, J4.S
unnamed: D1.2 (A), L2.1, U3.2
unnamed: D1.1 (K), R7.1, U3.1
unnamed: J1.7 (GCLK0/GPIO4), P1.3
unnamed: J1.29 (GCLK1/GPIO5), U2.13 (DB6)
unnamed: J1.31 (GCLK2/GPIO6), U2.12 (DB5)
unnamed: J1.8 (GPIO14/TXD), R5.1
unnamed: J1.10 (GPIO15/RXD), R8.2, U3.4
unnamed: J1.36 (GPIO16), U2.6 (E)
unnamed: ENC1.S1, J1.11 (GPIO17)
unnamed: J1.12 (GPIO18/PWM0), U1.13 (BCK)
unnamed: J1.35 (GPIO19/MISO1), U1.15 (LRCK)
unnamed: J1.40 (GPIO21/SCLK1), U1.14 (DIN)
unnamed: ENC1.A, J1.15 (GPIO22)
unnamed: J1.16 (GPIO23), P1.8
unnamed: J1.18 (GPIO24), P1.9
unnamed: J1.22 (GPIO25), P1.11
unnamed: J1.37 (GPIO26), U2.11 (DB4)
unnamed: ENC1.B, J1.13 (GPIO27)
unnamed: J1.21 (MISO0/GPIO9), P1.12
unnamed: J1.19 (MOSI0/GPIO10), P1.10
unnamed: J1.32 (PWM0/GPIO12), VR1.3
unnamed: J1.33 (PWM1/GPIO13), U2.15 (A/VEE)
unnamed: J1.23 (SCLK0/GPIO11), P1.13
unnamed: J1.5 (SCL/GPIO3), P1.6
unnamed: J1.3 (SDA/GPIO2), P1.5
unnamed: J1.24 (~CE0/GPIO8), U2.14 (DB7)
unnamed: J1.26 (~CE1/GPIO7), U2.4 (RS)
unnamed: J2.1, L2.2
unnamed: J2.2, J4.T
unnamed: J2.3, J4.R1
unnamed: J2.4, L1.2
unnamed: J3.1, L4.2
unnamed: J3.2, J5.T
unnamed: J3.3, J5.R1
unnamed: J3.4, L3.2
unnamed: L1.1, R7.2
unnamed: L3.1, R6.2
unnamed: L4.1, R5.2
unnamed: P1.4, R3.1
unnamed: P1.7, R4.1
unnamed: TRS1.TN, TRS2.R
unnamed: C5.2, U1.4 (CAPM)
unnamed: C5.1, U1.2 (CAPP)
unnamed: C2.1, C4.2, U1.18 (LDOO)
unnamed: R1.1, U1.6 (OUTL)
unnamed: R2.1, U1.7 (OUTR)
unnamed: C6.2, U1.5 (VNEG)
unnamed: U2.3 (VO), VR1.2

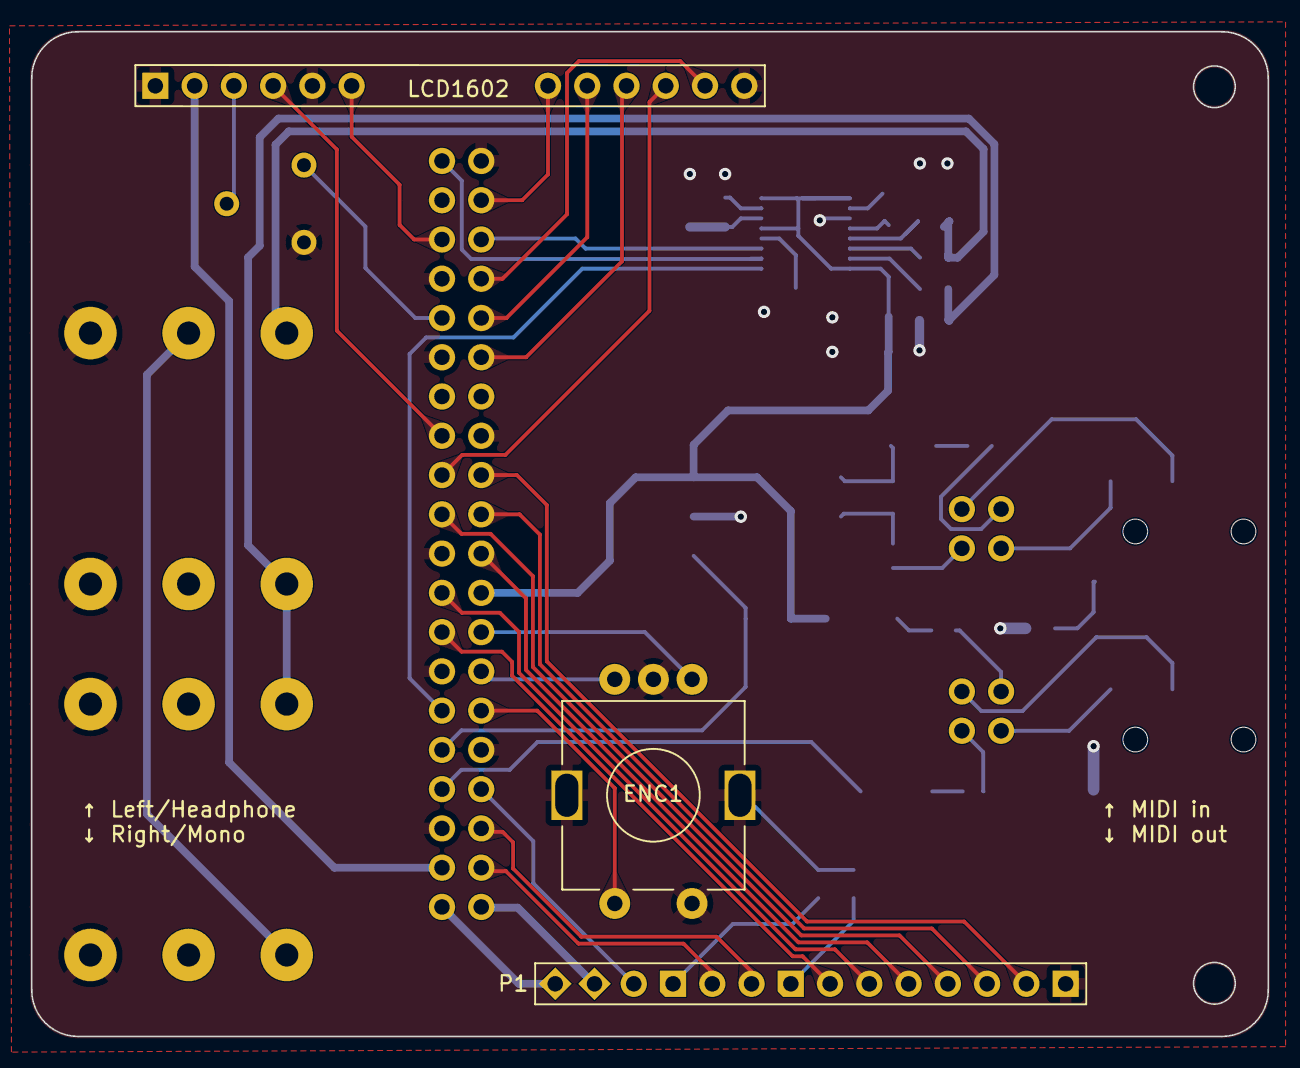
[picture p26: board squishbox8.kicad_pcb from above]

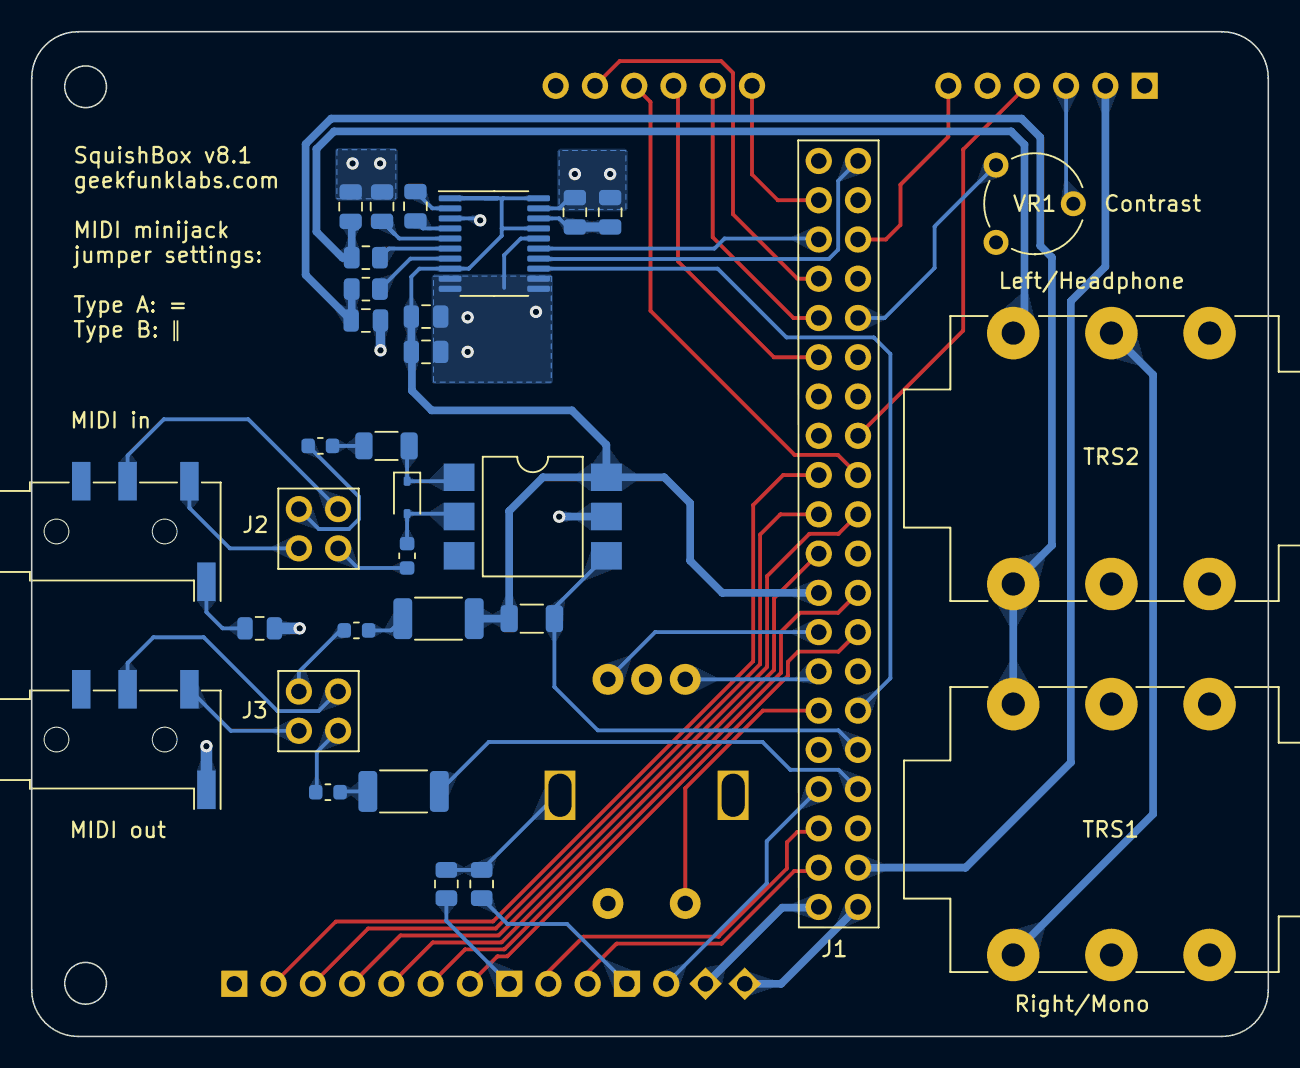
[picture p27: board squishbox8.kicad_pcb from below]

Board: 2 copper layers, 80.0 x 65.0 mm, 35 parts (32 on the bottom side), 56 nets.

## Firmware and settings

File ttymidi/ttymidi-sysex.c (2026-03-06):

/*
	This file is part of ttymidi.

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
	*new* by cchaussat
	Original ttymidi source code v0.60 (from Feb. 1st 2012)
	Taken from http://www.varal.org/ttymidi/ttymidi.tar.gz
	Using tutorial from http://www.qlcplus.org/forum/viewtopic.php?t=14337

	History of changes (at least as I can rebuild it from the various forums ...)

	****************************
	Modified 2014 by Johnty Wang
	****************************
	This is a slightly modified version of ttymidi, designed for a very
	specific purpose: to create a sysex bridge between a microcontroller
	that communicates sensor data via a USB serial port, and software
	running the same computer that communicates. It was designed to work with
	Infusion's ICubeX digitizers which can be configured and operated via sysex data

	The original ttymidi application only expected to parse and send MIDI data,
	and does not do anything when it receives sysex data. This version, on the other
	hand, *only* passes sysex messages back and forth between the serial and virtual midi ports

	The other change from original ttymidi code is that the MIDI por type being created:
	the bit SND_SEQ_PORT_TYPE_MIDI_GENERIC was added so that the virtual port
	shows up when searching for ports in ofxMidi

	to compile: gcc ttymidi.c -o ttymidi -lasound -pthread

	Created December 2014 by Johnty Wang [johntywang@infusionsystems.com]

	**************************
	Modified 2017 by sixeight7
	**************************
	The original ttymidi application did not support sysex messages. This version does.
	Based it on the work of johnty/ttymidi-icubex.c (see https://gist.github.com/johnty/de8b3d3041c7ee43accd)

	**************************
	Modified 2019 by ElBartoME
	**************************
	ttymidi with SysEx support (for MT-32) (see https://github.com/ElBartoME/ttymidi)
	I modified ttymidi in order to be able to process SysEx messages.
	This is crucial for some applications (like using Munt).
	I only implemented in one direction for now (Midi serial -> ALSA) as that is the only thing important for Munt.
	The code is based on sixeight7's code (https://github.com/sixeight7/ttymidi). His code unfortunately didn't work correctly.

	**************************
	Modified 2021 by cchaussat
	**************************
	Based on ElBartoME's code (based on sixeight7's code (based on Johnty Wang's code (based on original ttymidi code v0.60)))
	Now full operation midi + full bi-directional sysex operation, done by merging/tweaking some of JW's code into EB's new code
	Cleaned up all midi and sysex buffers and data casting to unsigned char (otherwise <0 char values sometimes appear as 4-byte FFFFFFnn data)
	All midi data prints formatted homogeneously and in hexadecimal (mix of decimal and hex was confusing)
	All prints to stdout flushed immediately
	Remaining issue : the non-midi text command FF 00 00 most of the times does not display the whole text message, seems to interfere with something

	See tags *new* on changes wrt original ttymidi code and/or JW's or EB's code (I did not use sixeight7's code at all)
	To compile: gcc ttymidi-sysex.c -o ttymidi-sysex -lasound -lpthread
*/


#include <stdlib.h>
#include <string.h>
#include <sys/types.h>
#include <sys/stat.h>
#include <fcntl.h>
#include <termios.h>
#include <stdio.h>
#include <argp.h>
#include <alsa/asoundlib.h>
#include <signal.h>
#include <pthread.h>
// Linux-specific
#include <linux/serial.h>
#include <linux/ioctl.h>
#include <asm/ioctls.h>
#include <time.h>

#define FALSE               0
#define TRUE                1

#define MAX_DEV_STR_LEN    32
#define MAX_MSG_SIZE     1024
#define BUF_SIZE         1024  // Size of the serial midi buffer - determines the maximum size of sysex messages *new*

/* change this definition for the correct port */
//#define _POSIX_SOURCE 1 /* POSIX compliant source */

int run;
int serial;
int port_out_id;

/* --------------------------------------------------------------------- */
// Program options

static struct argp_option options[] =
{
	{"serialdevice" , 's', "DEV" , 0, "Serial device to use. Default = /dev/ttyUSB0" },
	{"baudrate"     , 'b', "BAUD", 0, "Serial port baud rate. Default = 115200" },
	{"verbose"      , 'v', 0     , 0, "For debugging: Produce verbose output" },
	{"printonly"    , 'p', 0     , 0, "Super debugging: Print values read from serial -- and do nothing else" },
	{"quiet"        , 'q', 0     , 0, "Don't produce any output, even when the print command is sent" },
	{"name"		, 'n', "NAME", 0, "Name of the Alsa MIDI client. Default = ttymidi" },
	{ 0 }
};

typedef struct _arguments
{
	int  silent, verbose, printonly;
	char serialdevice[MAX_DEV_STR_LEN];
	int  baudrate;
	char name[MAX_DEV_STR_LEN];
} arguments_t;

void exit_cli(int sig)
{
	run = FALSE;
	printf("\nttymidi closing down...");
}

static error_t parse_opt (int key, char *arg, struct argp_state *state)
{
	/* Get the input argument from argp_parse, which we
	   know is a pointer to our arguments structure. */
	arguments_t *arguments = state->input;
	int baud_temp;

	switch (key)
	{
		case 'p':
			arguments->printonly = 1;
			break;
		case 'q':
			arguments->silent = 1;
			break;
		case 'v':
			arguments->verbose = 1;
			break;
		case 's':
			if (arg == NULL) break;
			strncpy(arguments->serialdevice, arg, MAX_DEV_STR_LEN);
			break;
		case 'n':
			if (arg == NULL) break;
			strncpy(arguments->name, arg, MAX_DEV_STR_LEN);
			break;
		case 'b':
			if (arg == NULL) break;
			baud_temp = strtol(arg, NULL, 0);
			if (baud_temp != EINVAL && baud_temp != ERANGE)
				switch (baud_temp)
				{
					case 1200   : arguments->baudrate = B1200  ; break;
					case 2400   : arguments->baudrate = B2400  ; break;
					case 4800   : arguments->baudrate = B4800  ; break;
					case 9600   : arguments->baudrate = B9600  ; break;
					case 19200  : arguments->baudrate = B19200 ; break;
					case 38400  : arguments->baudrate = B38400 ; break;
					case 57600  : arguments->baudrate = B57600 ; break;
					case 115200 : arguments->baudrate = B115200; break;
					default: printf("Baud rate %i is not supported.\n",baud_temp); exit(1);
				}

		case ARGP_KEY_ARG:
		case ARGP_KEY_END:
			break;

		default:
			return ARGP_ERR_UNKNOWN;
	}

	return 0;
}

void arg_set_defaults(arguments_t *arguments)
{
	char *serialdevice_temp = "/dev/serial0";
	arguments->printonly    = 0;
	arguments->silent       = 0;
	arguments->verbose      = 0;
	arguments->baudrate     = B38400;
	char *name_tmp		= (char *)"MIDI";
	strncpy(arguments->serialdevice, serialdevice_temp, MAX_DEV_STR_LEN);
	strncpy(arguments->name, name_tmp, MAX_DEV_STR_LEN);
}

const char *argp_program_version     = "ttymidi 0.60";
const char *argp_program_bug_address = "tvst@hotmail.com";
static char doc[]       = "ttymidi - Connect serial port devices to ALSA MIDI programs!";
static struct argp argp = { options, parse_opt, 0, doc };
arguments_t arguments;


/* --------------------------------------------------------------------- */
// MIDI stuff

int open_seq(snd_seq_t** seq)
{
	int port_out_id, port_in_id; // actually port_in_id is not needed nor used anywhere

	if (snd_seq_open(seq, "default", SND_SEQ_OPEN_DUPLEX, 0) < 0)
	{
		fprintf(stderr, "Error opening ALSA sequencer.\n");
		exit(1);
	}

	snd_seq_set_client_name(*seq, arguments.name);
	
	char nameInput[MAX_DEV_STR_LEN];
	strcpy(nameInput, arguments.name);
	strcat(nameInput, " In");

	if ((port_out_id = snd_seq_create_simple_port(*seq, nameInput,
					SND_SEQ_PORT_CAP_READ|SND_SEQ_PORT_CAP_SUBS_READ,
					SND_SEQ_PORT_TYPE_MIDI_GENERIC|SND_SEQ_PORT_TYPE_APPLICATION)) < 0)  // *new*
	{
		fprintf(stderr, "Error creating sequencer MIDI out port.\n");  // *new*
	}
	
	char nameOutput[MAX_DEV_STR_LEN];
	strcpy(nameOutput, arguments.name);
	strcat(nameOutput, " Out");

	if ((port_in_id = snd_seq_create_simple_port(*seq, nameOutput,
					SND_SEQ_PORT_CAP_WRITE|SND_SEQ_PORT_CAP_SUBS_WRITE,
					SND_SEQ_PORT_TYPE_MIDI_GENERIC|SND_SEQ_PORT_TYPE_APPLICATION)) < 0)  // *new*
	{
		fprintf(stderr, "Error creating sequencer MIDI in port.\n");  // *new*
	}

	return port_out_id;
}

void parse_midi_command(snd_seq_t* seq, int port_out_id, unsigned char *buf, int buflen)  // *new*
{
/*
	MIDI COMMANDS
	-------------------------------------------------------------------
	name                 status      param 1          param 2
	-------------------------------------------------------------------
	note off             0x80+C       key #            velocity
	note on              0x90+C       key #            velocity
	poly key pressure    0xA0+C       key #            pressure value
	control change       0xB0+C       control #        control value
	program change       0xC0+C       program #        --
	mono key pressure    0xD0+C       pressure value   --
	pitch bend           0xE0+C       range (LSB)      range (MSB)
	system               0xF0+C       manufacturer     model
	-------------------------------------------------------------------
	C is the channel number, from 0 to 15;
	-------------------------------------------------------------------
	source: http://ftp.ec.vanderbilt.edu/computermusic/musc216site/MIDI.Commands.html

	In this program the pitch bend range will be transmitter as
	one single 8-bit number. So the end result is that MIDI commands
	will be transmitted as 3 bytes, starting with the operation byte:

	buf[0] --> operation/channel
	buf[1] --> param1
	buf[2] --> param2        (param2 not transmitted on program change or key press)
*/

	snd_seq_event_t ev;
	snd_seq_ev_clear(&ev);
	snd_seq_ev_set_direct(&ev);
	snd_seq_ev_set_source(&ev, port_out_id);
	snd_seq_ev_set_subs(&ev);

	unsigned char operation, channel, param1, param2;  // *new* was int in original code
	int int_param1;  // *new*

	operation = buf[0] & 0xF0;
	channel   = buf[0] & 0x0F;
	param1    = buf[1] & 0xFF;  // *new* (protection ?)
	param2    = buf[2] & 0xFF;  // *new* (protection ?)

	switch (operation)
	{
		case 0x90:  // *new* handle noteon first to speed up the mostly used message
			if (!arguments.silent && arguments.verbose) {
				printf("Serial  %02X Note on            %02X %02X %02X\n", operation, channel, param1, param2);
				fflush(stdout);  // *new*
			}
			snd_seq_ev_set_noteon(&ev, channel, param1, param2);
			break;

		case 0x80:
			if (!arguments.silent && arguments.verbose) {
				printf("Serial  %02X Note off           %02X %02X %02X\n", operation, channel, param1, param2);
				fflush(stdout);  // *new*
			}
			snd_seq_ev_set_noteoff(&ev, channel, param1, param2);
			break;

		case 0xA0:
			if (!arguments.silent && arguments.verbose) {
				printf("Serial  %02X Pressure change    %02X %02X %02X\n", operation, channel, param1, param2);
				fflush(stdout);  // *new*
			}
			snd_seq_ev_set_keypress(&ev, channel, param1, param2);
			break;

		case 0xB0:
			if (!arguments.silent && arguments.verbose) {
				printf("Serial  %02X Controller change  %02X %02X %02X\n", operation, channel, param1, param2);
				fflush(stdout);  // *new*
			}
			snd_seq_ev_set_controller(&ev, channel, param1, param2);
			break;

		case 0xC0:
			if (!arguments.silent && arguments.verbose) {
				printf("Serial  %02X Program change     %02X %02X\n", operation, channel, param1);
				fflush(stdout);  // *new*
			}
			snd_seq_ev_set_pgmchange(&ev, channel, param1);
			break;

		case 0xD0:
			if (!arguments.silent && arguments.verbose) {
				printf("Serial  %02X Channel press      %02X %02X\n", operation, channel, param1);
				fflush(stdout);  // *new*
			}
			snd_seq_ev_set_chanpress(&ev, channel, param1);
			break;

		case 0xE0:
			int_param1 = (int) (param1 & 0x7F) + ((param2 & 0x7F) << 7);  // *new*
			if (!arguments.silent && arguments.verbose) {
				printf("Serial  %02X Pitch bend         %02X %04X\n", operation, channel, int_param1);  // *new*
				fflush(stdout);  // *new*
			}
			snd_seq_ev_set_pitchbend(&ev, channel, int_param1 - 8192); // in alsa MIDI we want signed int *new*
			break;

		case 0xF0:  // *new*
			switch (channel) {
				case 0x0:
					if (!arguments.silent && arguments.verbose) {
						printf("Serial  %02X Sysex len = %04X   ", operation, buflen);  // *new*
						int i;
						for (i=0; i < buflen; i++) {
							printf("%02X ", buf[i]);
						}
						printf("\n");
						fflush(stdout);  // *new*
					}
					// Send sysex message
					snd_seq_ev_set_sysex(&ev, buflen, buf);
					break;
				case 0x1: // MTC Quarter Frame package
					if (!arguments.silent && arguments.verbose) {
						printf("Serial  MTC Quarter Frame       %02x\n", param1);
						fflush(stdout);  // *new*
					}
					snd_seq_ev_set_fixed(&ev);
					ev.data.control.value = param1;
					ev.type = SND_SEQ_EVENT_QFRAME;
					break;
				case 0x2: // Song Position
					int_param1 = (int) (param1 & 0x7F) + ((param2 & 0x7F) << 7);  // *new*
					if (!arguments.silent && arguments.verbose) {
						printf("Serial  Song Position           %04x\n", int_param1);
						fflush(stdout);  // *new*
					}
					snd_seq_ev_set_fixed(&ev);
					ev.data.control.value = int_param1;
					ev.type = SND_SEQ_EVENT_SONGPOS;
					break;
				case 0x3: // Song Select
					if (!arguments.silent && arguments.verbose) {
						printf("Serial  Song Select             %02x\n", param1);
						fflush(stdout);  // *new*
					}
					snd_seq_ev_set_fixed(&ev);
					ev.data.control.value = param1;
					ev.type = SND_SEQ_EVENT_SONGSEL;
					break;
				case 0x6: // Tune Request
					if (!arguments.silent && arguments.verbose) {
						printf("Serial  Tune Request\n");
						fflush(stdout);  // *new*
					}
					snd_seq_ev_set_fixed(&ev);
					ev.type = SND_SEQ_EVENT_TUNE_REQUEST;
					break;
				case 0x8: // Clock
					if (!arguments.silent && arguments.verbose) {
						printf("Serial  Clock\n");
						fflush(stdout);  // *new*
					}
					snd_seq_ev_set_fixed(&ev);
					ev.type = SND_SEQ_EVENT_CLOCK;
					break;
				case 0xA: // Start
					if (!arguments.silent && arguments.verbose) {
						printf("Serial  Start\n");
						fflush(stdout);  // *new*
					}
					snd_seq_ev_set_fixed(&ev);
					ev.type = SND_SEQ_EVENT_START;
					break;
				case 0xB: // Continue
					if (!arguments.silent && arguments.verbose) {
						printf("Serial  Continue\n");
						fflush(stdout);  // *new*
					}
					snd_seq_ev_set_fixed(&ev);
					ev.type = SND_SEQ_EVENT_CONTINUE;
					break;
				case 0xC: // Stop
					if (!arguments.silent && arguments.verbose) {
						printf("Serial  Stop\n");
						fflush(stdout);  // *new*
					}
					snd_seq_ev_set_fixed(&ev);
					ev.type = SND_SEQ_EVENT_STOP;
					break;
				case 0xE: // Active sense
					if (!arguments.silent && arguments.verbose) {
						printf("Serial  Active sense\n");
						fflush(stdout);  // *new*
					}
					snd_seq_ev_set_fixed(&ev);
					ev.type = SND_SEQ_EVENT_SENSING;
					break;

				default:
					if (!arguments.silent) {  // *new*
						printf("Serial  %02X Unknown MIDI System cmd\n", buf[0] & 0xFF);  // *new*
						fflush(stdout);  // *new*
					}
					break;
			}
			break;

		default:
			if (!arguments.silent) {  // *new*
				printf("Serial  %02X Unknown MIDI cmd   %02X %02X %02X\n", operation, channel, param1, param2);  // *new*
				fflush(stdout);  // *new*
			}
			break;
	}

	snd_seq_event_output_direct(seq, &ev);
	snd_seq_drain_output(seq);
}
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
int main(int argc, char** argv)  // *new* int to remove compilation warning
{
	//arguments arguments;
	struct termios oldtio, newtio;
	struct serial_struct ser_info;
	char* modem_device = "/dev/ttyS0";
	snd_seq_t *seq;

	arg_set_defaults(&arguments);
	argp_parse(&argp, argc, argv, 0, 0, &arguments);

	/*
	 * Open MIDI output port
	 */

	port_out_id = open_seq(&seq);

	/*
	 *  Open modem device for reading and not as controlling tty because we don't
	 *  want to get killed if linenoise sends CTRL-C.
	 */

	serial = open(arguments.serialdevice, O_RDWR | O_NOCTTY );

	if (serial < 0)
	{
		perror(arguments.serialdevice);
		exit(-1);
	}

	/* save current serial port settings */
	tcgetattr(serial, &oldtio);

	/* clear struct for new port settings */
	bzero(&newtio, sizeof(newtio));

	/*
	 * BAUDRATE : Set bps rate. You could also use cfsetispeed and cfsetospeed.
	 * CRTSCTS  : output hardware flow control (only used if the cable has
	 * all necessary lines. See sect. 7 of Serial-HOWTO)
	 * CS8      : 8n1 (8bit, no parity, 1 stopbit)
	 * CLOCAL   : local connection, no modem contol
	 * CREAD    : enable receiving characters
	 */
	newtio.c_cflag = arguments.baudrate | CS8 | CLOCAL | CREAD; // CRTSCTS removed

	/*
	 * IGNPAR  : ignore bytes with parity errors
	 * ICRNL   : map CR to NL (otherwise a CR input on the other computer
	 * will not terminate input)
	 * otherwise make device raw (no other input processing)
	 */
	newtio.c_iflag = IGNPAR;

	/* Raw output */
	newtio.c_oflag = 0;

	/*
	 * ICANON  : enable canonical input
	 * disable all echo functionality, and don't send signals to calling program
	 */
	newtio.c_lflag = 0; // non-canonical

	/*
	 * set up: we'll be reading 4 bytes at a time.
	 */
	newtio.c_cc[VTIME]    = 0;  /* inter-character timer unused */
	newtio.c_cc[VMIN]     = 1;  /* blocking read until n character arrives */

	/*
	 * now clean the modem line and activate the settings for the port
	 */
	tcflush(serial, TCIFLUSH);
	tcsetattr(serial, TCSANOW, &newtio);

	// Linux-specific: enable low latency mode (FTDI "nagling off")
//	ioctl(serial, TIOCGSERIAL, &ser_info);
//	ser_info.flags |= ASYNC_LOW_LATENCY;
//	ioctl(serial, TIOCSSERIAL, &ser_info);

	if (arguments.printonly)
	{
		printf("Super debug mode: Only printing the signal to screen. Nothing else.\n");
	}

	/*
	 * read commands
	 */

	/* Starting thread that is polling alsa midi in port */
	pthread_t midi_out_thread, midi_in_thread;
	int iret1, iret2;
	run = TRUE;
	iret1 = pthread_create(&midi_out_thread, NULL, read_midi_from_alsa, (void*) seq);
	/* And also thread for polling serial data. As serial is currently read in
		blocking mode, by this we can enable ctrl+c quiting and avoid zombie
		alsa ports when killing app with ctrl+z */
	iret2 = pthread_create(&midi_in_thread, NULL, read_midi_from_serial_port, (void*) seq);
	signal(SIGINT, exit_cli);
	signal(SIGTERM, exit_cli);

	while (run)
	{
		sleep(100);
	}

	void* status;
	pthread_join(midi_out_thread, &status);

	/* restore the old port settings */
	tcsetattr(serial, TCSANOW, &oldtio);
	printf("\ndone!\n");
}

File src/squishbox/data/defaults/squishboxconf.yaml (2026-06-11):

menu_time: 3
hold_time: 1.0
scroll_time: 0.2
scroll_pause: 3
menu_timeout: 3.0
frame_time: 0.1
poll_time: 0.01
button_debounce: 0.02
encoder_debounce: 0.002
gpio_chip: /dev/gpiochip4
pull_up: true
lcd_rows: 2
lcd_cols: 16
lcd_regsel: 7
lcd_enable: 16
lcd_data: [26, 6, 5, 8]
lcd_exec_time: 5.0e-05
controls:
  knob1:
    type: encoder
    pins: [22, 27]
    actions: {left: dec, right: inc}
  knob1_button:
    type: button
    pin: 17
    actions: {tap: select, hold: back}
  foot_left:
    type: button
    pin: 9
    messages: {in: ctrl:16:22:127, out: ctrl:16:22:0}
  foot_right:
    type: button
    pin: 11
    messages: {in: ctrl:16:23:127, out: ctrl:16:23:0}
outputs:
  contrast: {type: pwm, pin: 12, level: 100}
  backlight: {type: pwm, pin: 13, level: 100}
  led_left: {type: binary, pin: 4}
  led_right: {type: binary, pin: 23}
glyphs_5x8:
  check: |
    -----
    ----X
    ---XX
    X-XX-
    XXX--
    -X---
    -----
    -----
  cross: |
    -----
    XX-XX
    -XXX-
    --X--
    -XXX-
    XX-XX
    -----
    -----
  wifi_on: |
    -XXX-
    X---X
    --X--
    -X-X-
    -----
    --X--
    -----
    -----
  wifi_off: |
    -X-X-
    --X--
    -X-X-
    -----
    --X--
    -----
    --X--
    -----
  note: |
    --X--
    --XX-
    --X-X
    --X-X
    --X--
    XXX--
    XXX--
    -----
midi_connections:
- any>any
app_dirs: ["~/SquishBox/apps",]

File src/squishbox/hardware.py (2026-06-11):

"""SquishBox Raspberry Pi hardware interface.

Provides low-level access to GPIO-backed hardware components used by
SquishBox, including buttons, rotary encoders, LCD display, and outputs.

Also implements event-driven input handling and a buffered LCD rendering
system with support for scrolling, blinking, and custom glyphs.

Requires:
    - gpiod
"""
from contextlib import contextmanager
from datetime import timedelta
from threading import Thread
import time

import gpiod

from .config import CONFIG


ROWS = CONFIG["lcd_rows"]
COLS = CONFIG["lcd_cols"]


class Control:
    """Base class for input controls with event binding.

    Provides a simple event → callback mapping. Subclasses trigger
    events (e.g. "tap", "left") which invoke the bound functions.
    """

    def __getitem__(self, val):
        """Return the bound callback for an event (or no-op if unbound)."""
        return self._actions.get(val, lambda: None)

    def release(self):
        self._watching = False
        self._thread.join()
        self._req.release()

    def bind(self, event, func):
        """Bind a callback function to an event.

        Args:
            event (hashable): Event identifier
            func (callable): function to invoke, or None to remove binding.
        """
        if func == None:
            self._actions.pop(event, None)
        else:
            self._actions[event] = func

    def clear_binds(self):
        """Remove all event bindings."""
        self._actions = {}


class Button(Control):
    """GPIO button with tap/hold detection.

    Monitors a GPIO input line and emits events based on press duration.

    Events:
      - "down": button pressed
      - "up": button released
      - "in"/"out": toggles on button press
      - "tap": short press
      - "hold": long press (duration >= CONFIG["hold_time"])
    """
    UP, DOWN, HELD = 0, 1, 2

    def __init__(self, pin, pull_up=CONFIG["pull_up"]):
        """Initialize button input and start event watcher thread.

        Args:
            pin (int): GPIO pin number.
            pull_up (bool): Whether to enable pull-up (else pull-down).
        """
        if pull_up:
            bias = gpiod.line.Bias.PULL_UP
        else:
            bias = gpiod.line.Bias.PULL_DOWN
        self._req = gpiod.request_lines(
            CONFIG["gpio_chip"],
            consumer="squishbox",
            config={
                pin: gpiod.LineSettings(
                    direction=gpiod.line.Direction.INPUT,
                    edge_detection=gpiod.line.Edge.BOTH,
                    bias=bias,
                    debounce_period=timedelta(
                        seconds=CONFIG["button_debounce"]
                    )
                )
            }
        )
        self._state = self.UP
        self._toggle = False
        self._actions = {}
        self._watching = True
        self._thread = Thread(
            target=lambda: self._watch(pin, pull_up),
            daemon=True
        )
        self._thread.start()

    def _watch(self, pin, pull_up):
        if pull_up:
            connect = gpiod.EdgeEvent.Type.FALLING_EDGE
            disconnect = gpiod.EdgeEvent.Type.RISING_EDGE
        else:
            connect = gpiod.EdgeEvent.Type.RISING_EDGE
            disconnect = gpiod.EdgeEvent.Type.FALLING_EDGE
        while self._watching:
            if not self._req.wait_edge_events(0.1):
                continue
            for event in self._req.read_edge_events():
                if event.event_type is connect:
                    self._state = self.DOWN
                    self["down"]()
                    self._toggle = not self._toggle
                    self["in" if self._toggle else "out"]()
                    if not self._req.wait_edge_events(CONFIG["hold_time"]):
                        self._state = self.HELD
                        self["hold"]()
                elif event.event_type is disconnect:
                    self["up"]()
                    if self._state == self.DOWN:
                        self["tap"]()
                    self._state = self.UP


class Encoder(Control):
    """Quadrature rotary encoder.

    Detects rotation direction using two GPIO inputs.

    Events:
      - "left": counterclockwise rotation
      - "right": clockwise rotation
    """
    
    def __init__(self, pin1, pin2, pull_up=CONFIG["pull_up"]):
        """Initialize encoder inputs and start watcher thread.

        Args:
            pin1 (int): First GPIO pin.
            pin2 (int): Second GPIO pin.
            pull_up (bool): Whether to enable pull-up resistors.
        """
        if pull_up:
            bias = gpiod.line.Bias.PULL_UP
        else:
            bias = gpiod.line.Bias.PULL_DOWN
        self._req = gpiod.request_lines(
            CONFIG["gpio_chip"],
            consumer="squishbox",
            config={
                (pin1, pin2): gpiod.LineSettings(
                    direction=gpiod.line.Direction.INPUT,
                    edge_detection=gpiod.line.Edge.BOTH,
                    bias=bias,
                    debounce_period=timedelta(
                        seconds=CONFIG["encoder_debounce"]
                    )
                )
            }
        )
        self._edges = (0, 0)
        self._actions = {}
        self._watching = True
        self._thread = Thread(
            target=lambda: self._watch(pin1, pin2, pull_up),
            daemon=True
        )
        self._thread.start()

    def _watch(self, pin1, pin2, pull_up):
        s = int(pull_up)
        while self._watching:
            if not self._req.wait_edge_events(0.1):
                continue
            for event in self._req.read_edge_events():
                if event.event_type is event.Type.RISING_EDGE:
                    self._edges = (self._edges[-1], event.line_offset)
                elif event.event_type is event.Type.FALLING_EDGE:
                    self._edges = (self._edges[-1], -event.line_offset)
                if self._edges == (s * pin1, s * pin2):
                    self["left"]()
                elif self._edges == (s * pin2, s * pin1):
                    self["right"]()
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

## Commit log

2023-08-27 initial dump
    [squishbox-B_Cu.gbl, squishbox-B_Mask.gbs, squishbox-B_Paste.gbp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]
2023-08-27 flip model print side down
    [squishbox_box_v10-Box cover.stl]
2023-12-16 swap cursor modes in char_input()
    line cursor makes it easier to see characters when scrolling rapidly
    [squishbox.py]
2024-04-25 check for python3-rpi-lgpio package
    newer kernels with the gpiochip device need the python3-rpi-lgpio package to properly set edge detection. Checking for existence of this package seems the best way to determine whether it's needed
2025-08-13 initial rework for v0.9
    - update for use with libgpiod
    - clean up API
    - remove user need to poll, update LCD
    - add dynamic binding for buttons, controls
    [squishbox.py]
2025-09-15 add encoder debouncing
2025-09-15 skip PWM for level=0,100
    [squishbox.py]
2025-10-27 fix backlight/contrast state save
    [squishbox.py]
2025-10-31 fix typos and string conversions
    [squishbox.py]
2025-11-12 fix return value of menu_choose
    [squishbox.py]
2025-12-27 fix glyph redefinition bug
    [hardware.py]
2026-02-17 replace activity_* with contextmanager
    [hardware.py]
2026-03-11 fix raw strings in regex
    [keys.py, squishbox.py]
2026-04-04 remove usb mount service
2026-04-06 update hardware files
    [mini-case-lid.3mf, basic-case-body.3mf, basic-case-body.stl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]
2026-04-08 catch missing cfg file in load_config
    [config.py]
2026-04-09 Document P1 header pin functions in README
    Added details about the P1 header and its pin functions.
2026-05-04 keep current files when unpacking soundfonts
2026-05-07 catch errors loading banks/checking wifi
    [squishbox.py]
2026-05-15 add toggling "on"/"off" events for buttons
2026-05-17 fix regression in get_action()
    [squishbox.py]
2026-05-18 fix cursor properties access
    [squishbox.py]
2026-05-18 fix regression in cursor property access
    [hardware.py, squishbox.py]
2026-05-19 fix mutable default argument in load_config()
    [config.py]
2026-05-27 resolve yaml/button toggle syntax collision
    [hardware.py, squishboxconf.yaml]
2026-05-27 fix typing in ControlChangeEvent creation
    [midi.py]
2026-06-11 clarify LED installation
2026-06-13 allow specifying track end position
2026-06-16 add nopasswd rule for reboot, power off
2026-06-16 deprecate legacy power commands
2026-09-12 fix MIDI channel mapping for hardware controls
    [squishbox.py]

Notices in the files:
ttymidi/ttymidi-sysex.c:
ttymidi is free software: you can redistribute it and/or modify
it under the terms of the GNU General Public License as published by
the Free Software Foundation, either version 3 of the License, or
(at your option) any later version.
